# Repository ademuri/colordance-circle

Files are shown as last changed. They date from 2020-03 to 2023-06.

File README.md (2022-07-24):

# Colordance Circle

An art project that uses arrays of colored lights around a circle to create
kaleidoscopic colored shadows.

"This is not an officially supported Google product"

## Building

This project uses two build systems, PlatformIO and CMake. PIO is for code which
runs on embedded devices - these run the actual hardware. CMake is for running
tests on standard PCs.

To build with PlatformIO, run `pio run -e <env>`, where `<env>` is one defined
in [platformio.ini](platformio.ini) (e.g. `teensy`).

To run the tests:

```
mkdir -p build
cd build
cmake .. -DBUILD_SIMULATOR=false
make && ./generictest
```

### Simulator

The simulator uses SDL2 to render the LEDs. To build it, first install the SDL2 development library

`sudo apt install libsdl2-dev`

then, from the `build` directory, configure CMake to build it with

`cmake .. -DBUILD_SIMULATOR=true`

then build and run it with

`make && ./lib/simulator/Simulator`

#### Processing

To run the simulator with the Processing controller, from the build directory run:

```bash
${PROCESSING_HOME?}/processing-java --sketch=../controller/processing_controller --run | ./lib/simulator/Simulator
```

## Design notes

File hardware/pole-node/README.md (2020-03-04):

## Datasheets

- APA3211: [datasheet](https://www.diodes.com/assets/Datasheets/AP3211.pdf), [application notes](https://www.diodes.com/assets/Part-Support-Files/AP3211/6434133.pdf)

## Calculations

### Voltage regulator

- Feedback voltage is 0.81V. Use [this voltage divider calculator](http://www.ti.com/download/kbase/volt/volt_div3.htm). For E96, this yields 11500 and 2210 Ohms, which produces 5.02v.
- Inductor value: `L1 = 5V * (12V - 5V) / (1.4MHz * 12V * 1.5A * .26) = 5.3uH -> 5.6 uH`
- Peak inductor current: `1.5A + ((12V - 5V) * 5V) / (2 * 1.4MHz * 12V * 5.6uH) = 1.69A`
- Inductor current rating is `1.5 * 1.69A = 2.5A`
- Input ripple with 10uF cap: `1.5A / (1.4Mhz * 10uF) * (5V / 12V) * (1 - (5V / 12V)) = .026V`

### RS485 termination

- [Application note](http://www.ti.com/lit/an/snla034b/snla034b.pdf)
- AC termination should yield clean signal without significantly increasing power consumption
- Assuming 40' max cable length:
- `C<sub>T <= (40ft * 2 * 1.7ns/ft) / 100 Ohm = 1.36 nF`
- This yields an RC time constant of `136 ns`. At `800 kHz`, the signal period is `1.25 us`.

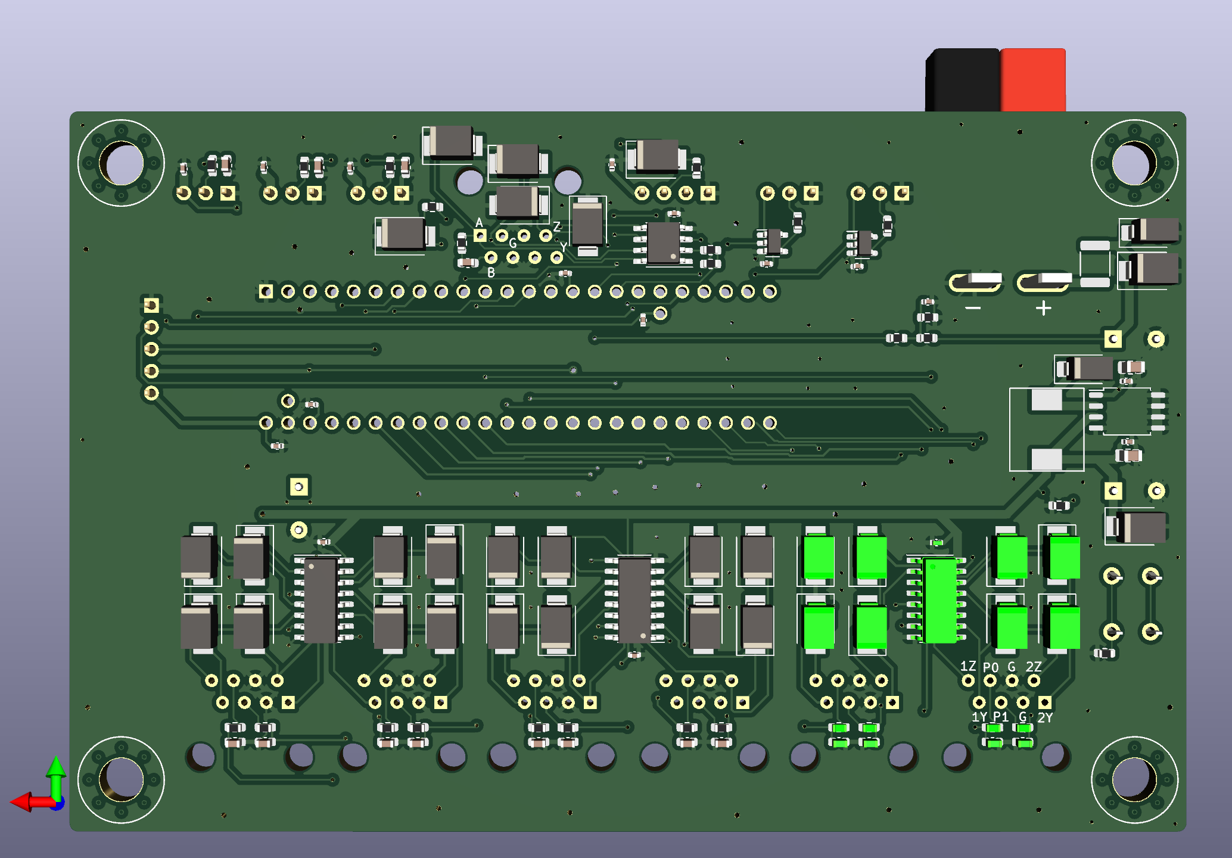
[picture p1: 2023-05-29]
hardware/colordance-brain/ref/colordance-brain back.png

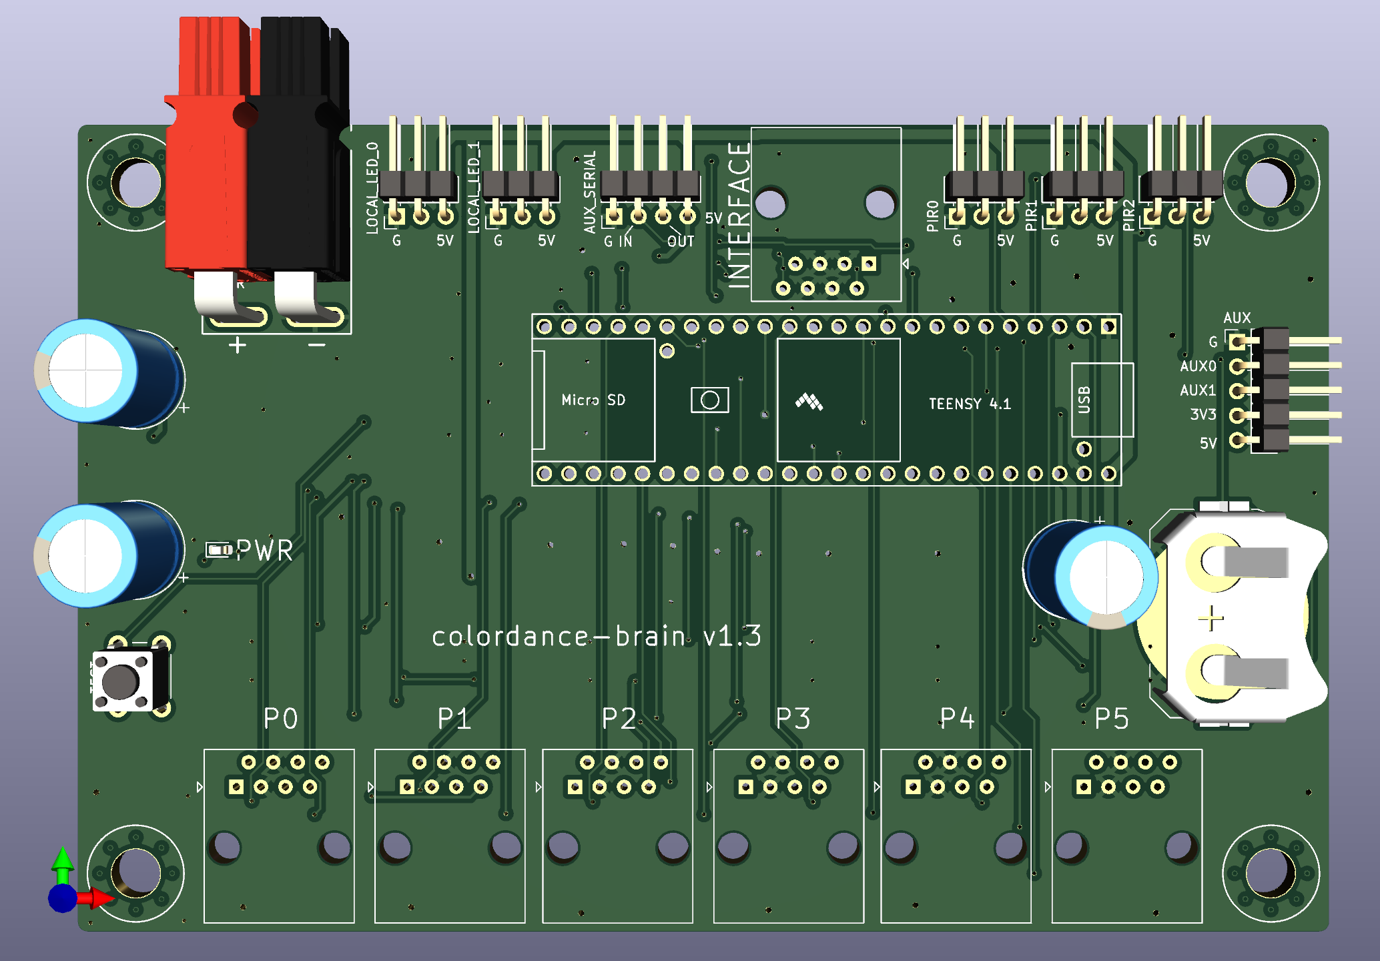
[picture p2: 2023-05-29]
hardware/colordance-brain/ref/colordance-brain front.png

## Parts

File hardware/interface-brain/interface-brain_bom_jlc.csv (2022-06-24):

Comment | Designator | Footprint | LCSC Part #
100nF | C1,C2,C3,C4,C8,C9,C10,C11,C12,C13,C14,C15,C16,C17,C18,C19,C20,C21,C22,C23,C28,C29,C30,C31,C32,C33,C34,C35,C40,C41,C42,C43,C48,C49,C50,C51,C55,C58,C60 | C_0402_1005Metric | C307331
10nF | C7 | C_0402_1005Metric | C15195
22nF | C24,C25,C26,C27,C36,C37,C38,C39,C44,C45,C46,C47,C52,C53 | C_0402_1005Metric | C1532
22uF | C54 | C_1206_3216Metric | C12891
1nF | C57 | C_0402_1005Metric | C1523
10uF | C61,C6,C59 | C_0805_2012Metric | C15850
SCHOTTKY | D2 | D_SMA | C8678
LED | D6 | LED_0603_1608Metric | C2286
D | D9 | D_SMA | C8678
10k | R1,R2,R3,R4,R25 | R_0603_1608Metric | C25804
120 | R7 | R_0603_1608Metric | C22787
33 | R9,R10,R11,R12,R13,R14,R15,R16,R17,R18,R19,R20,R21,R22,R23,R24 | R_0603_1608Metric | C23140
1k | R26,R27,R28,R29,R30,R31,R32,R33,R38,R39,R40,R41,R42,R43,R44,R45,R46,R47,R48,R49,R54,R55 | R_0603_1608Metric | C21190
SN74ACT244PWR | U1,U2 | TSSOP-20_4.4x6.5mm_P0.65mm | C6930

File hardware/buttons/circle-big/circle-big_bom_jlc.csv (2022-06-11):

Comment | Designator | Footprint | LCSC Part #
10uF | C1 | C_0603_1608Metric | C96446
100nF | C2 | C_0402_1005Metric | C307331
WS2812B | D1,D2,D3,D4,D5,D6,D7,D8,D9,D10,D11,D12 | LED_WS2812B_PLCC4_5.0x5.0mm_P3.2mm | C2761796
33 | R1,R2 | R_0603_1608Metric | C23140

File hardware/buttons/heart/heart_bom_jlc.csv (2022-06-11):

Comment | Designator | Footprint | LCSC Part #
10uF | C1 | C_0603_1608Metric | C96446
100nF | C2 | C_0402_1005Metric | C307331
WS2812B | D1,D2,D3,D4,D5,D6,D7,D8,D9,D10,D11,D12,D13,D14,D15 | LED_WS2812B_PLCC4_5.0x5.0mm_P3.2mm | C2761796
33 | R1,R2 | R_0603_1608Metric | C23140

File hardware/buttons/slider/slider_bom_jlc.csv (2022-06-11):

Comment | Designator | Footprint | LCSC Part #
10uF | C1 | C_0603_1608Metric | C96446
100nF | C2 | C_0402_1005Metric | C307331
WS2812B | D1,D2,D3 | LED_WS2812B_PLCC4_5.0x5.0mm_P3.2mm | C2761796
33 | R1 | R_0603_1608Metric | C23140

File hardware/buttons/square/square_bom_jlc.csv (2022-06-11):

Comment | Designator | Footprint | LCSC Part #
10uF | C1 | C_0603_1608Metric | C96446
100nF | C2 | C_0402_1005Metric | C307331
WS2812B | D1,D2,D3,D4 | LED_WS2812B_PLCC4_5.0x5.0mm_P3.2mm | C2761796
33 | R1,R2 | R_0603_1608Metric | C23140

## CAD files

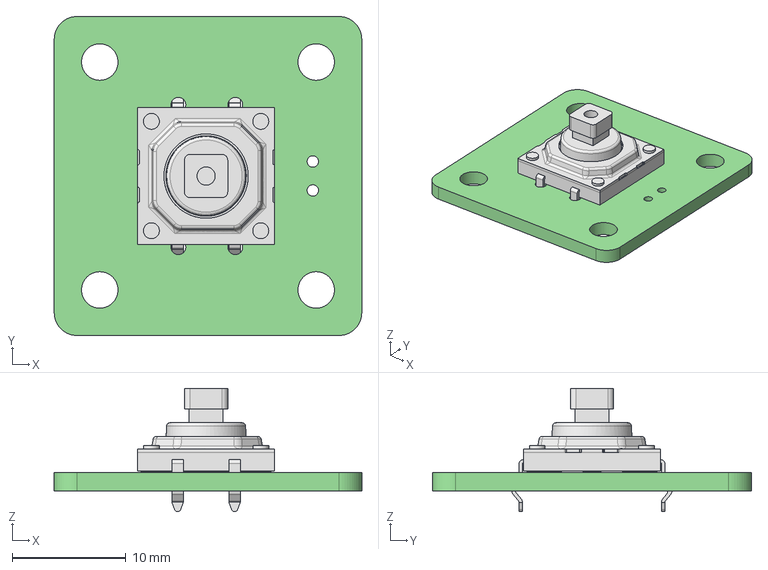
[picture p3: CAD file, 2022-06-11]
hardware/buttons/button-holder/button-holder.step
27.0 x 28.0 x 10.8 mm
button-holder PCB

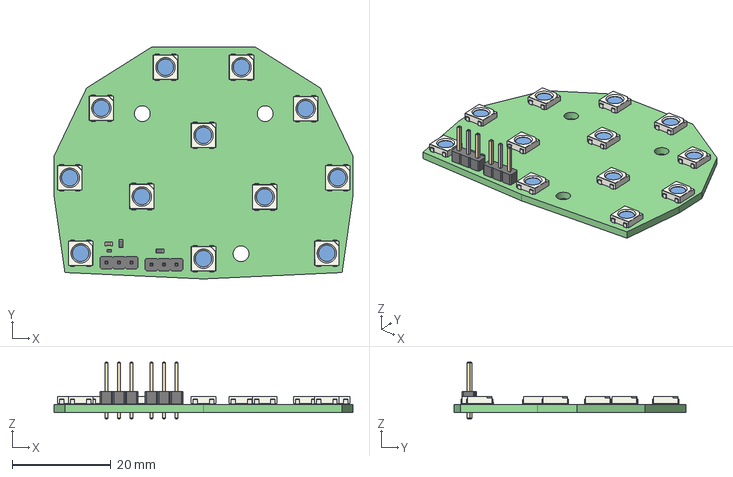
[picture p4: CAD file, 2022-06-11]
hardware/buttons/circle-big/circle-big.step
60.6 x 47.0 x 11.5 mm
circle-big PCB

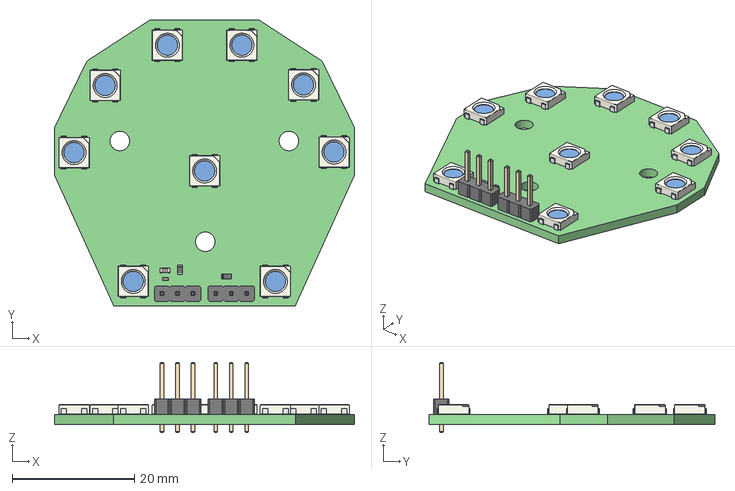
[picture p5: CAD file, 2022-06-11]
hardware/buttons/circle-small/circle-small.step
49.1 x 46.8 x 11.5 mm
circle-small PCB

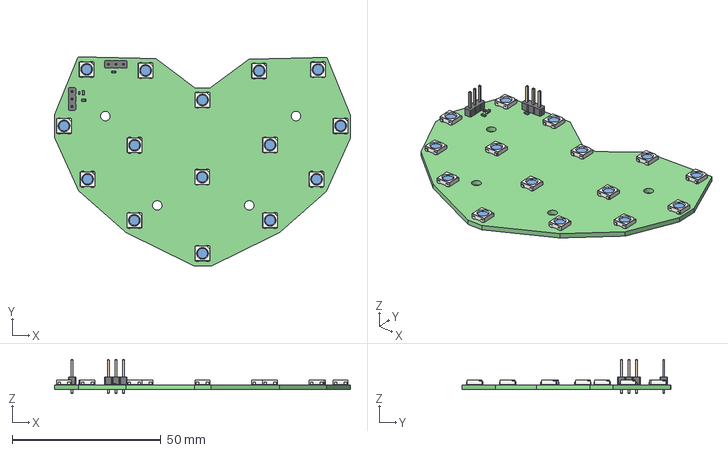
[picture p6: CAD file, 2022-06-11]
hardware/buttons/heart/heart.step
99.4 x 70.3 x 11.5 mm
heart PCB

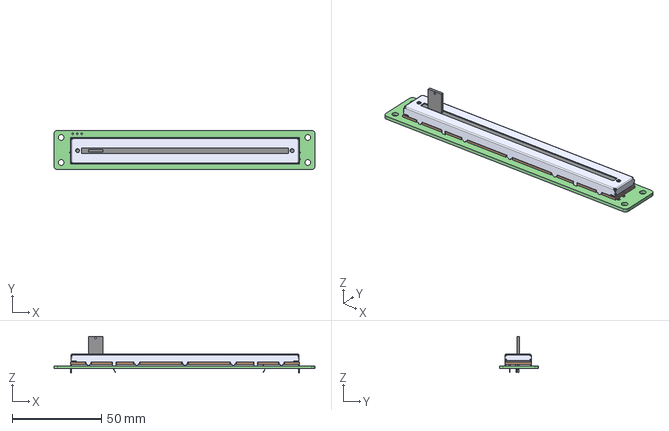
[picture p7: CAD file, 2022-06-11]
hardware/buttons/pot-holder/pot-holder.step
146.0 x 22.0 x 20.4 mm
pot-holder PCB

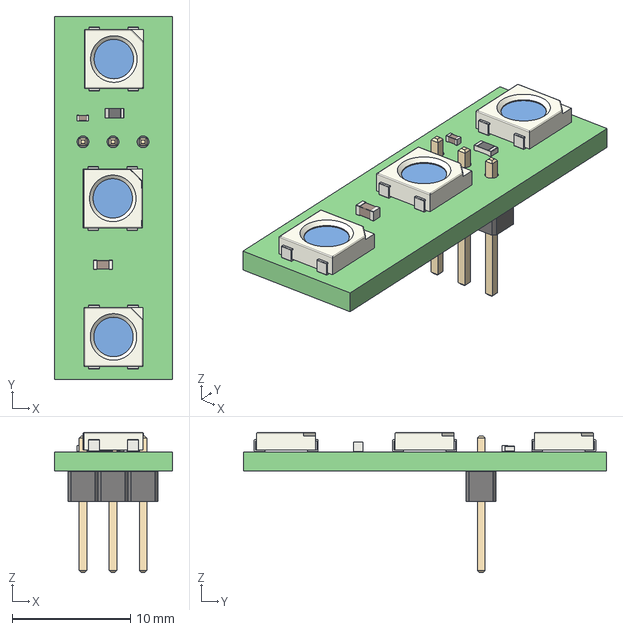
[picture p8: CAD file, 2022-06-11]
hardware/buttons/slider/slider.step
10.0 x 30.7 x 11.8 mm
slider PCB

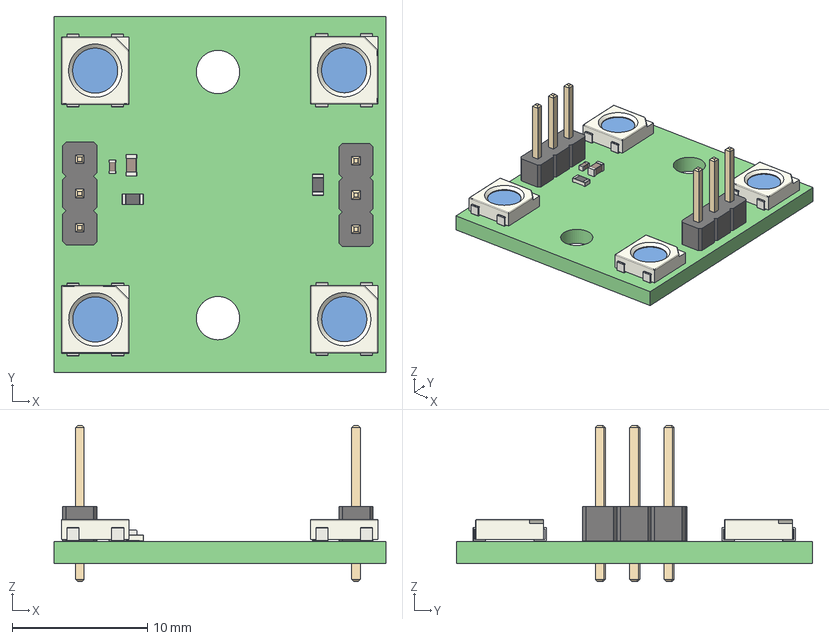
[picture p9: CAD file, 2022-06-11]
hardware/buttons/square/square.step
24.5 x 26.3 x 11.5 mm
square PCB

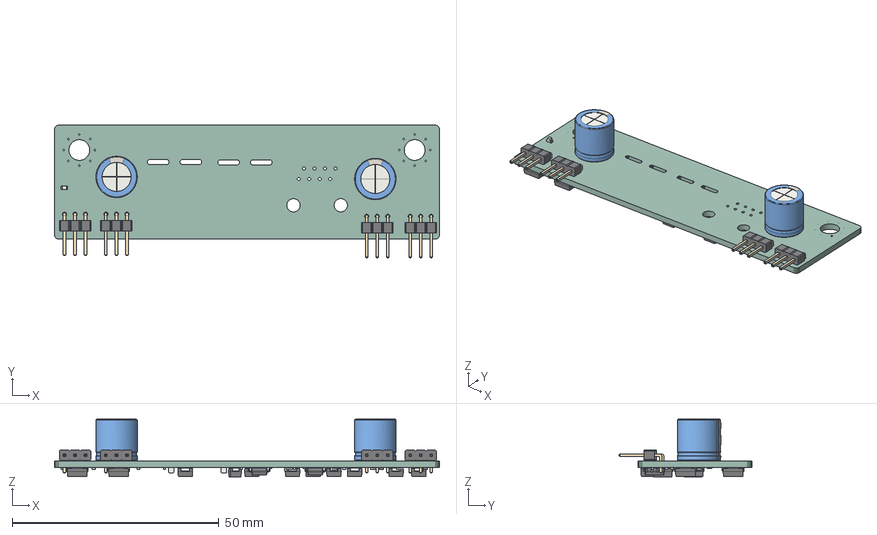
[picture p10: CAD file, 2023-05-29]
hardware/pole-node/ref/pole-node.step
93.0 x 32.0 x 13.9 mm
_autosave-pole-node PCB

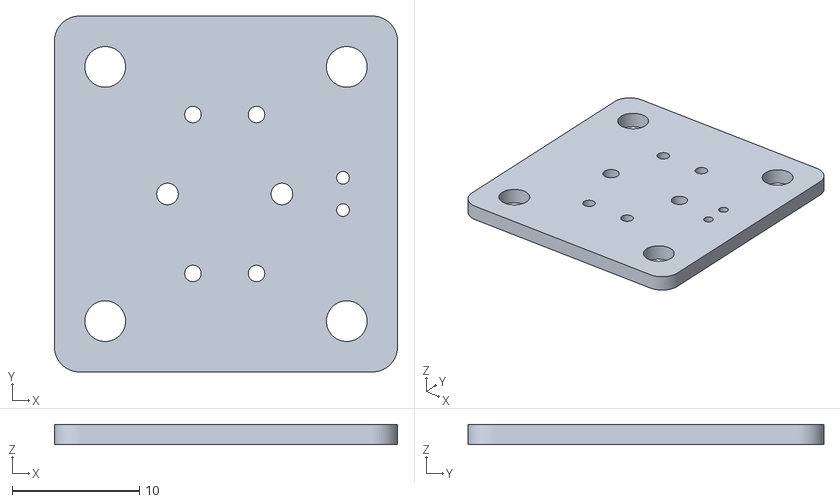
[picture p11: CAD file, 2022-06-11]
hardware/buttons/button-holder/button-holder PCB.stl
27.0 x 28.0 x 1.60

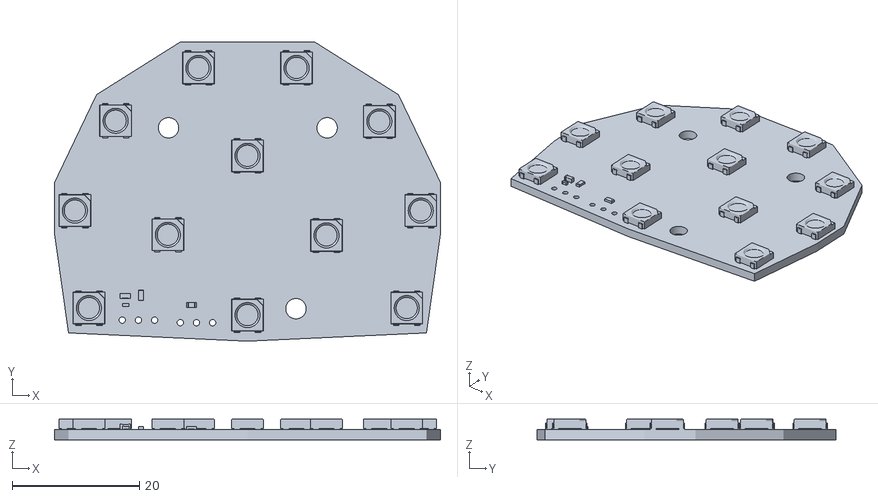
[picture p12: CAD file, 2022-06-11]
hardware/buttons/circle-big/circle-big v1.stl
60.6 x 47.0 x 3.25

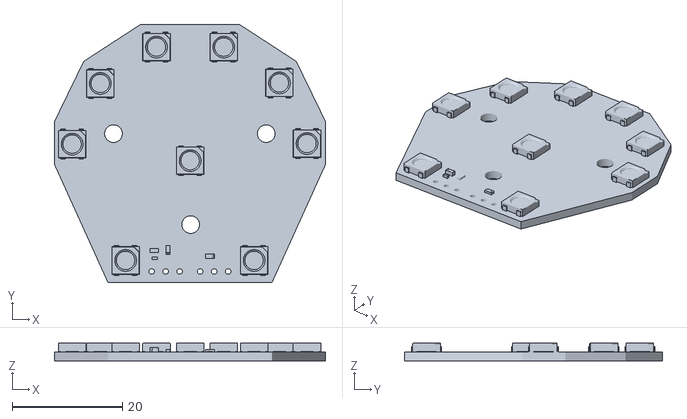
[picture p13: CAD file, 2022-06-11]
hardware/buttons/circle-small/circle-small v1.stl
49.2 x 46.8 x 3.25

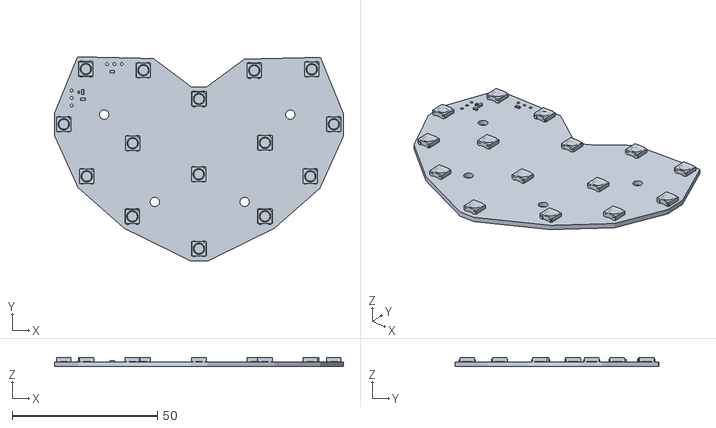
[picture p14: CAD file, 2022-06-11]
hardware/buttons/heart/heart v1.stl
99.4 x 70.3 x 3.25

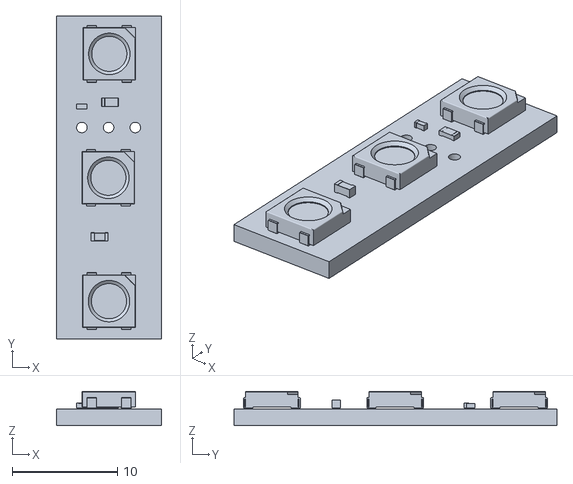
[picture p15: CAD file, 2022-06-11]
hardware/buttons/slider/slider v1.stl
10.0 x 30.7 x 3.25

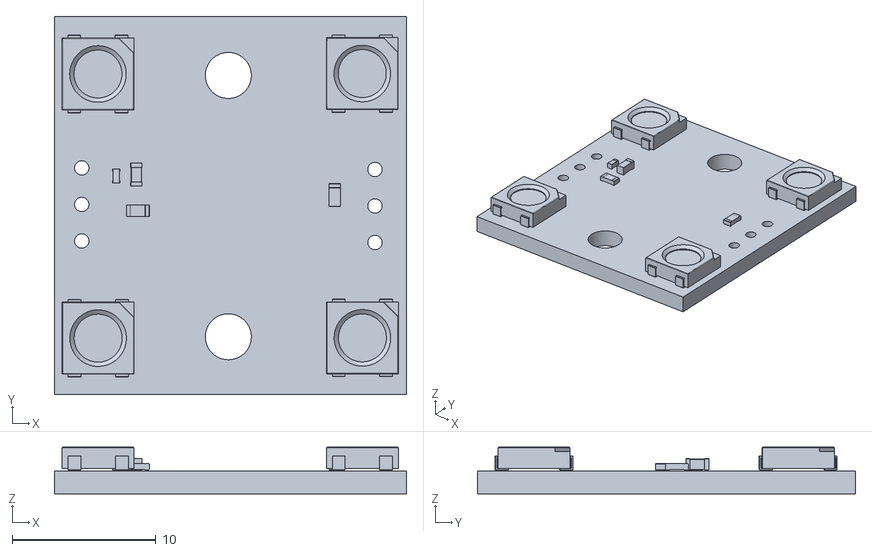
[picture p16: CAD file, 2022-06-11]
hardware/buttons/square/square v1.stl
24.5 x 26.3 x 3.25

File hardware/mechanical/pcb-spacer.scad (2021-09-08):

$fn = 200;

function inches(in) = in * 25.4;

module spacer(height, id, od) {
    linear_extrude(height = height) {
        difference() {
            circle(d = od);
            circle(d = id);
        }
    }
}

// #8 PCB spacer
//spacer(height = 6.35, od = 5 + 2 * 4, id = 5);

// 1/4-20 bolt washer
spacer(height = 1, id = inches(.257), od = inches(.257) + 2 * 4);

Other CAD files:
hardware/mechanical/pcb-spacer.stl
hardware/mechanical/quarter inch washer.stl

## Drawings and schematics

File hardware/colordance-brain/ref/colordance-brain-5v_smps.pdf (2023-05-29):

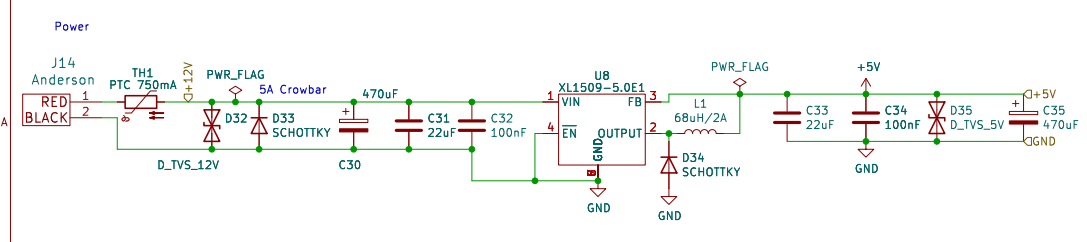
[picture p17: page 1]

Id: 5/5 Title: File: 5v_smps.kicad_sch Sheet: /5v_smps/

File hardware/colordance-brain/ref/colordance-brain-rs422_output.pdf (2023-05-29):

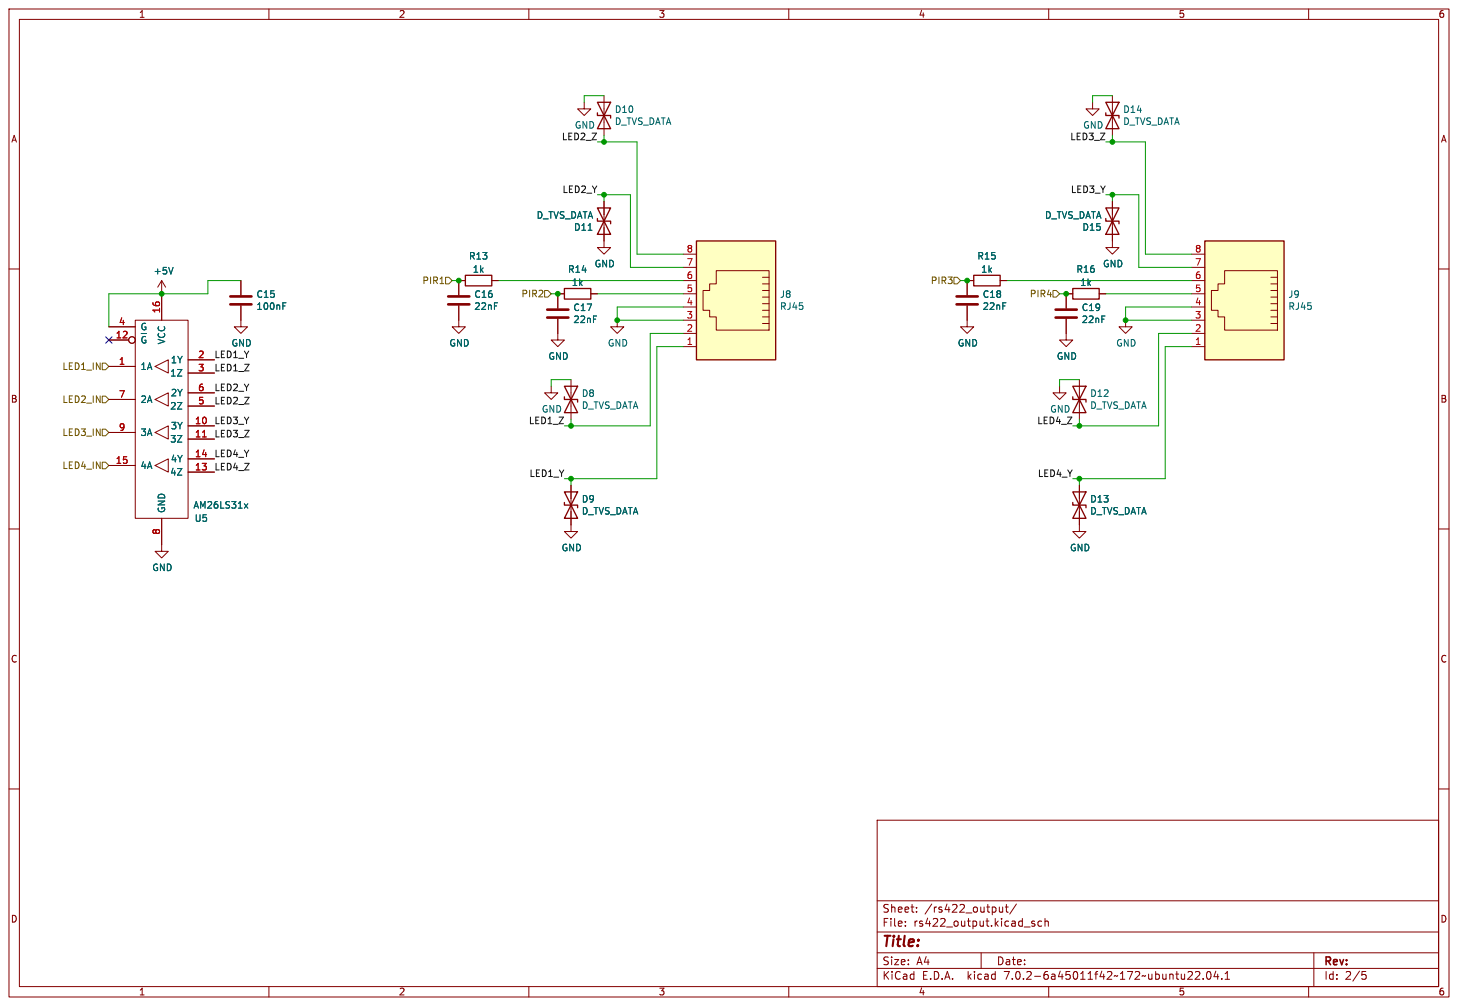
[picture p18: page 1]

Id: 2/5 Title: File: rs422_output.kicad_sch Sheet: /rs422_output/

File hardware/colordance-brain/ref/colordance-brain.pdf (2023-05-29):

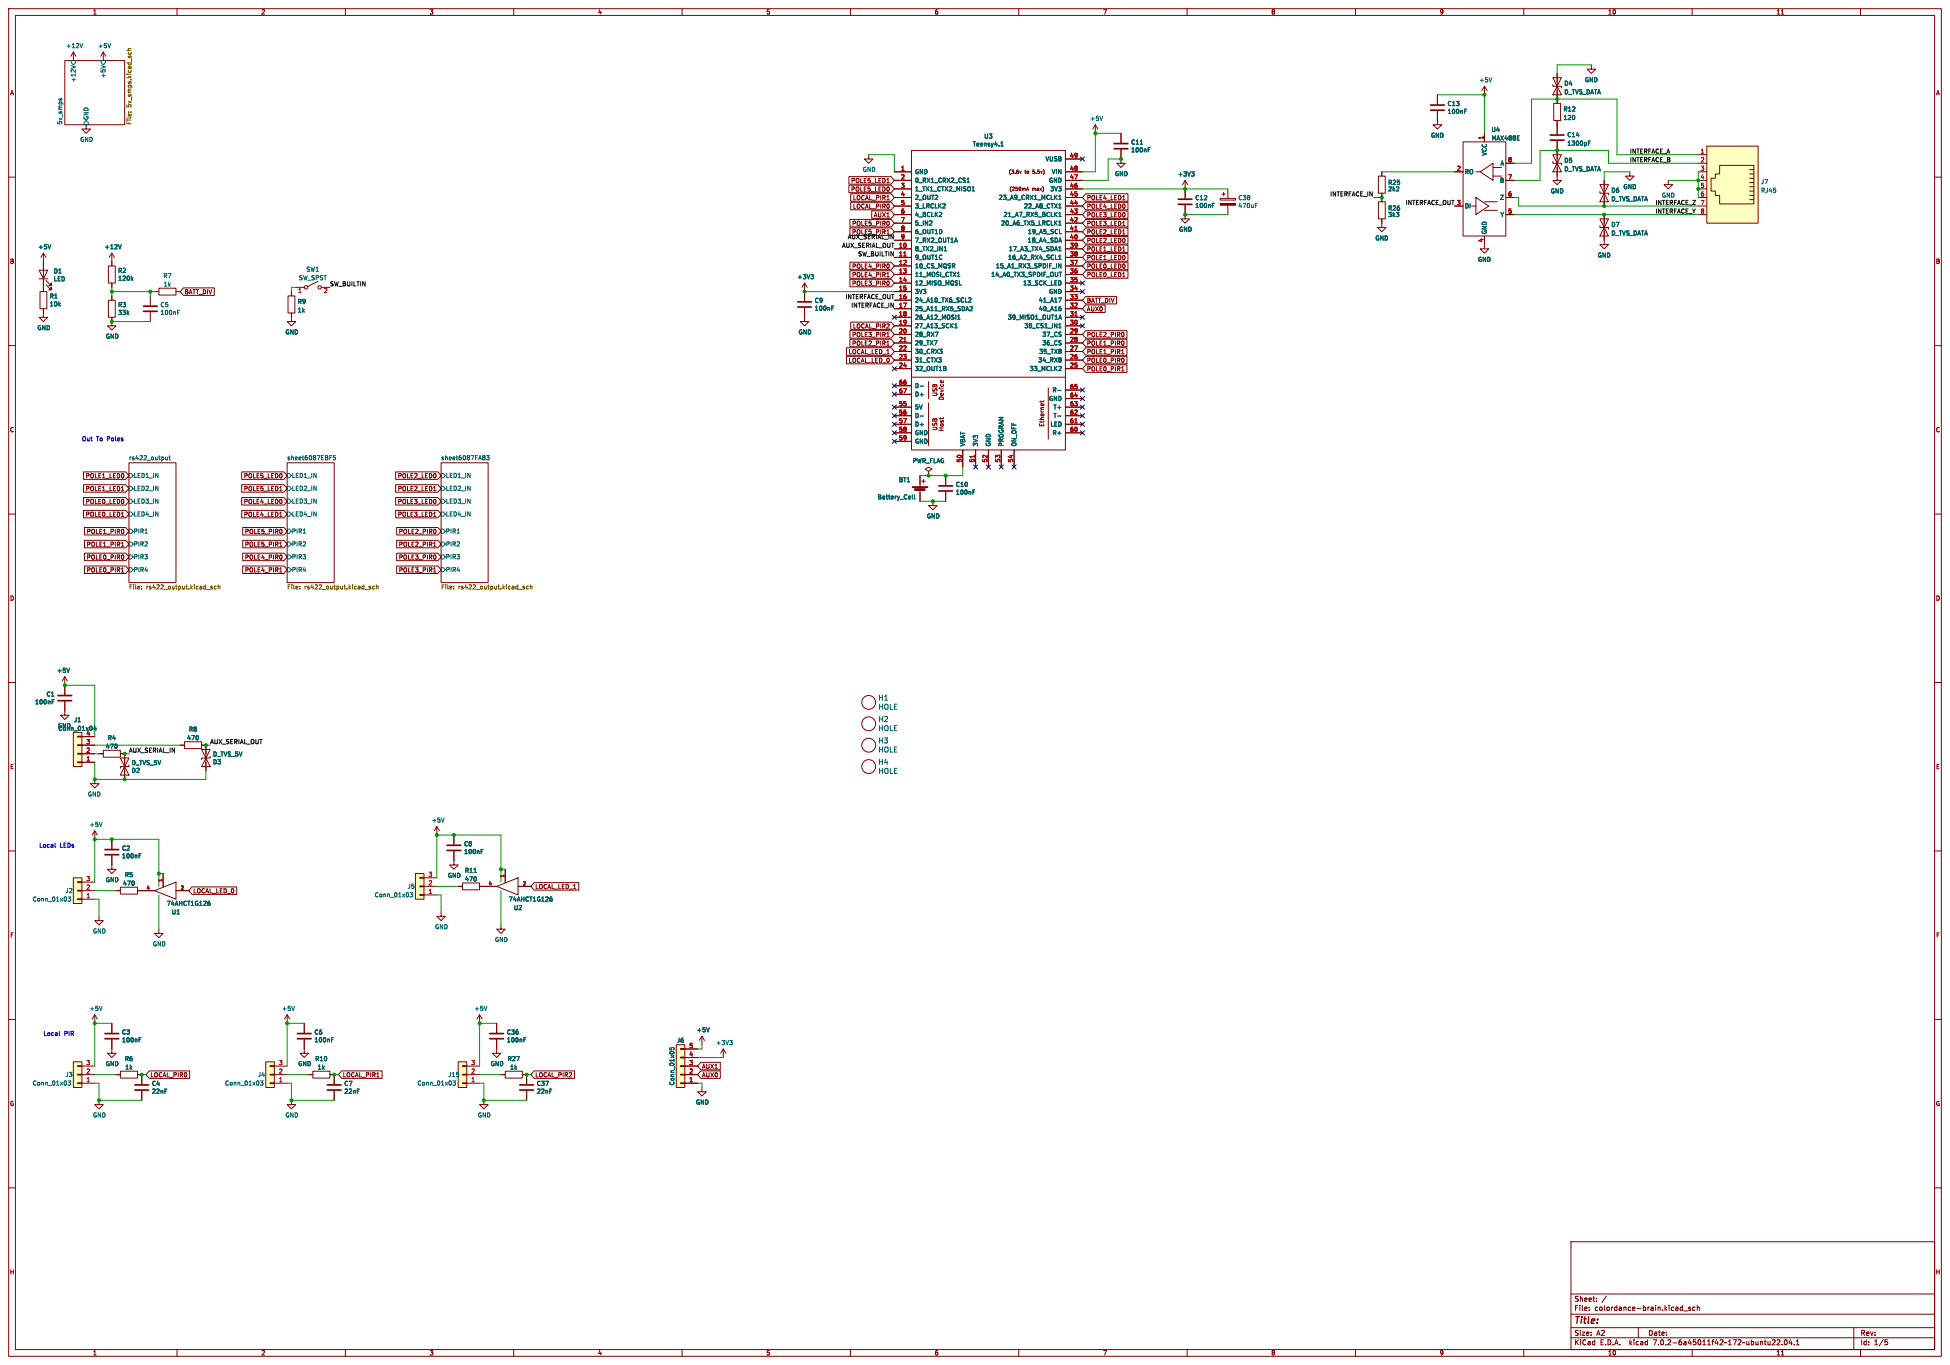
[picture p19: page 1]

GND
Local LEDs Local PIR

Id: 1/5 Title: File: colordance-brain.kicad_sch Sheet: /

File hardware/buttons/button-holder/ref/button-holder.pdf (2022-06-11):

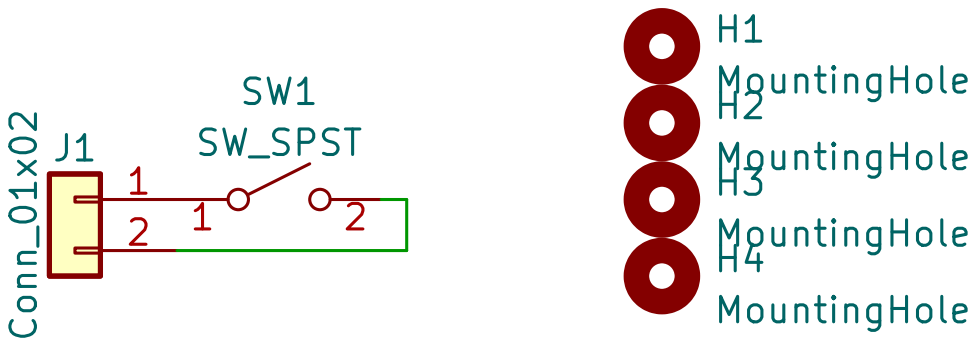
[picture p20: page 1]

File: button-holder.kicad_sch Sheet: /
Id: 1/1 Title:

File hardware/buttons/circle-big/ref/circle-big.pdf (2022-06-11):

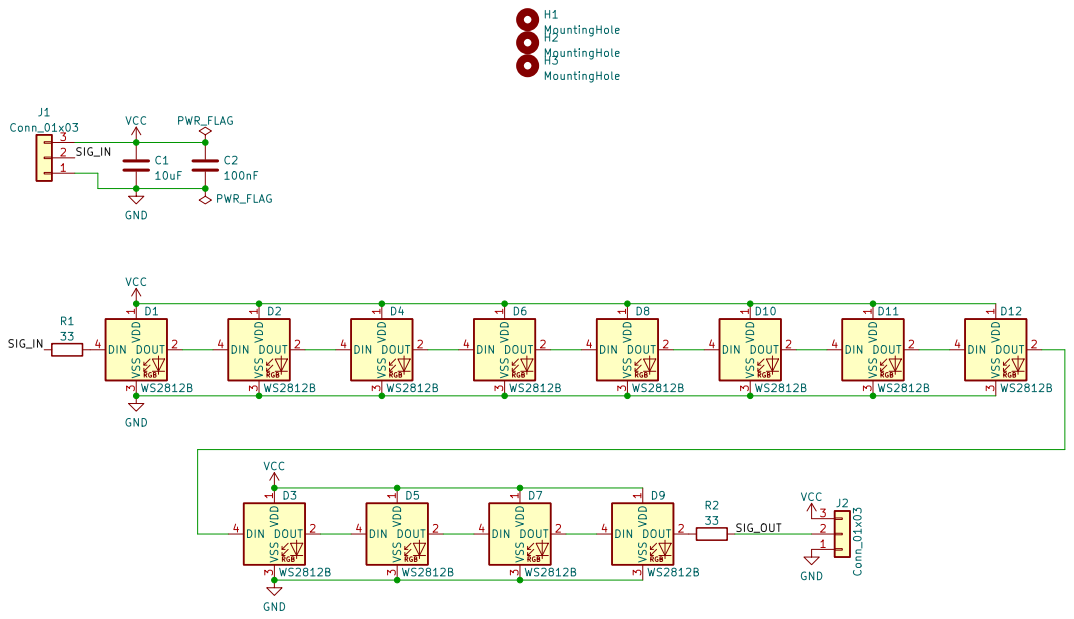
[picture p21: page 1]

File: circle-big.kicad_sch Sheet: /
Id: 1/1 Title:

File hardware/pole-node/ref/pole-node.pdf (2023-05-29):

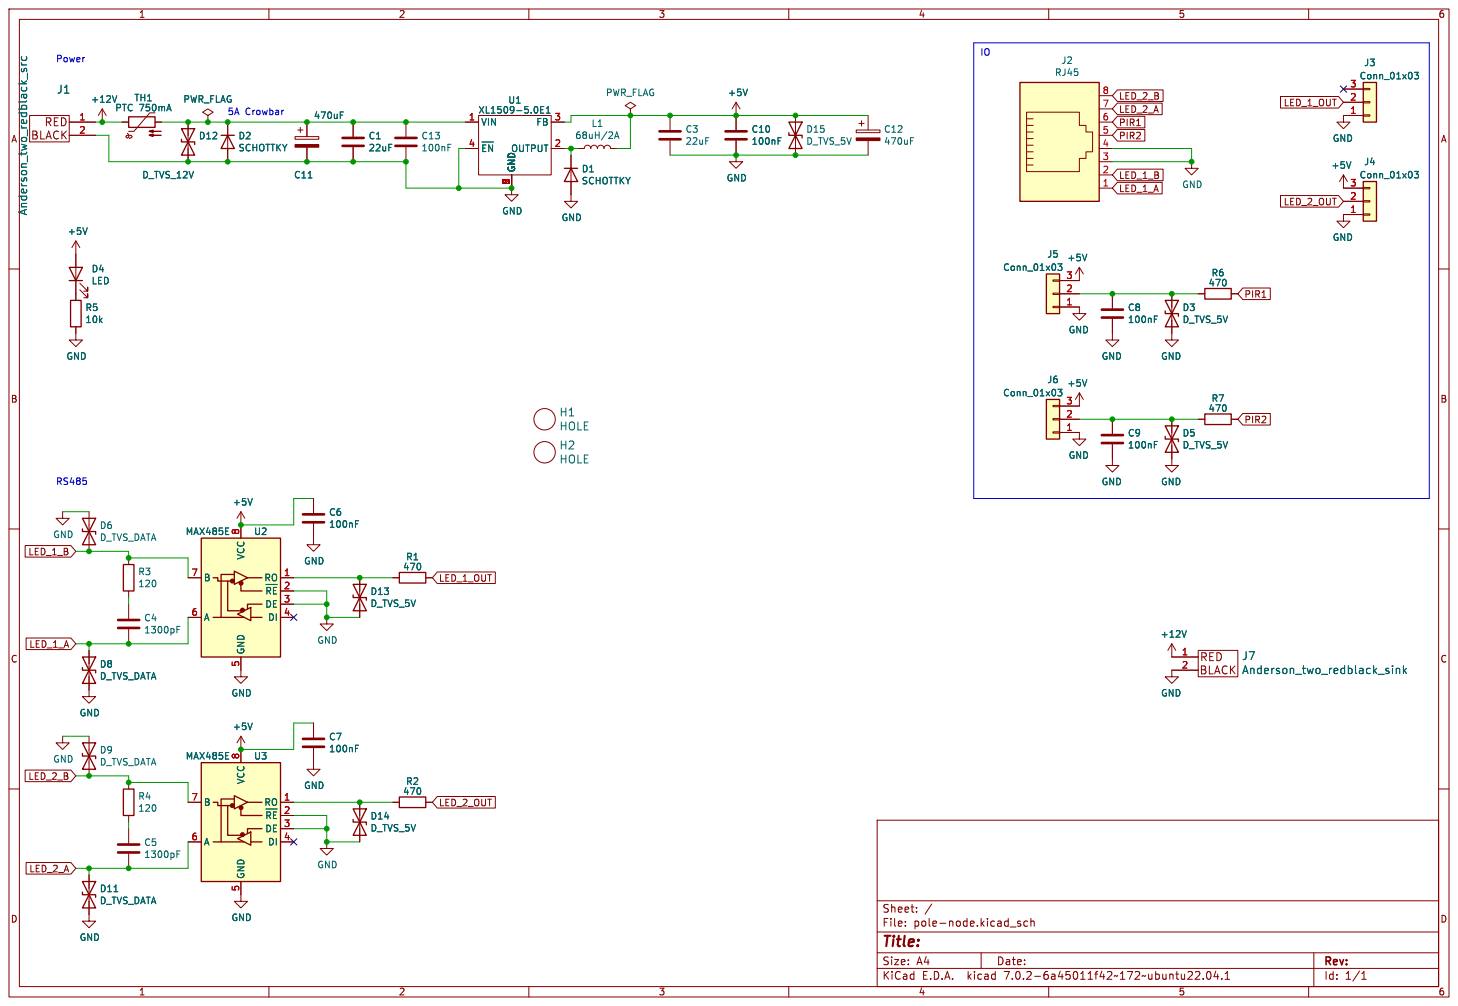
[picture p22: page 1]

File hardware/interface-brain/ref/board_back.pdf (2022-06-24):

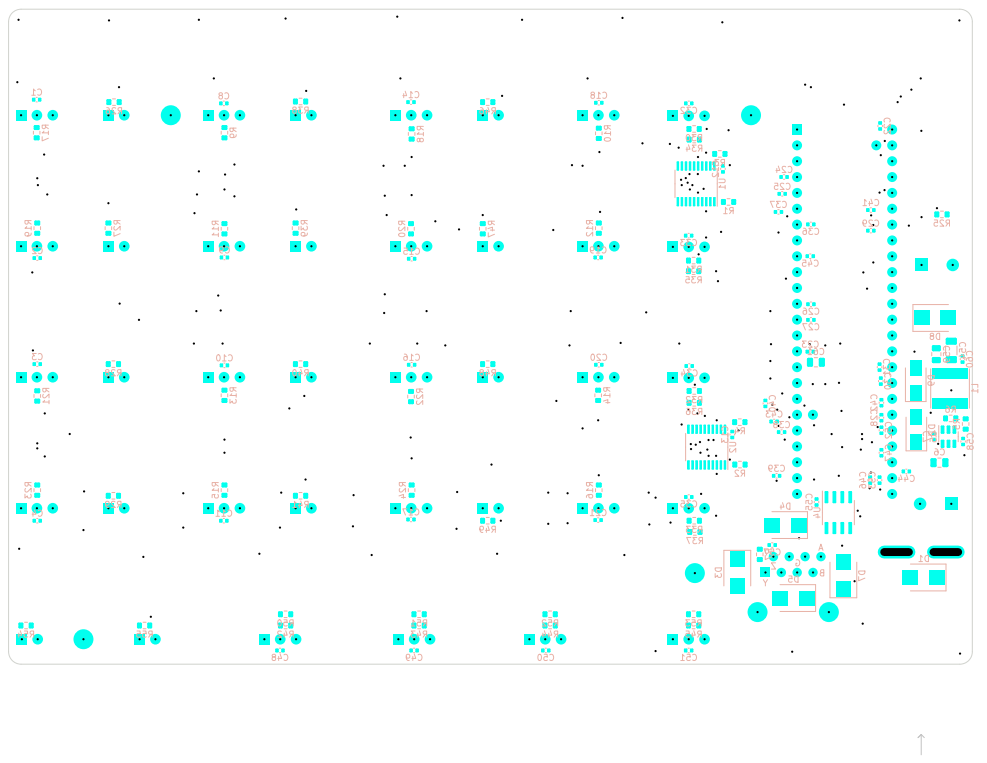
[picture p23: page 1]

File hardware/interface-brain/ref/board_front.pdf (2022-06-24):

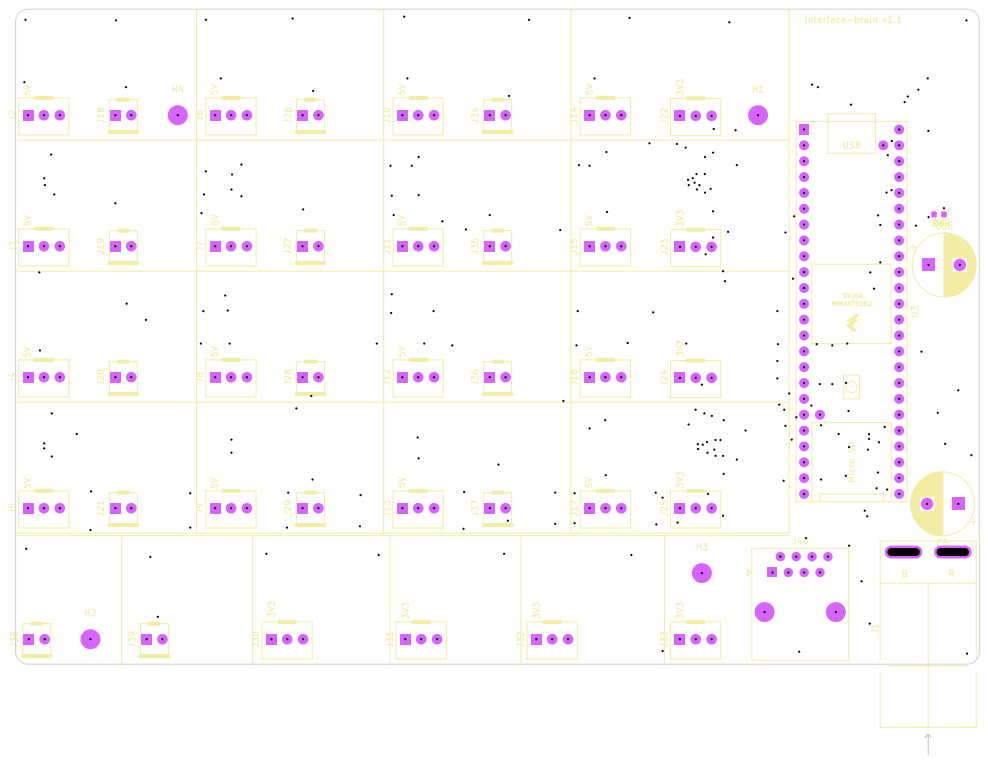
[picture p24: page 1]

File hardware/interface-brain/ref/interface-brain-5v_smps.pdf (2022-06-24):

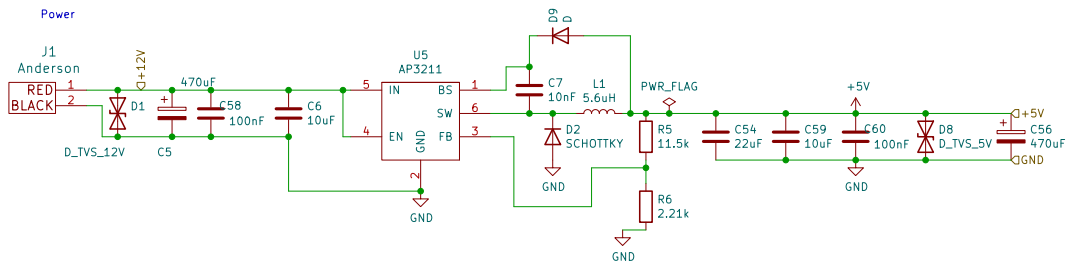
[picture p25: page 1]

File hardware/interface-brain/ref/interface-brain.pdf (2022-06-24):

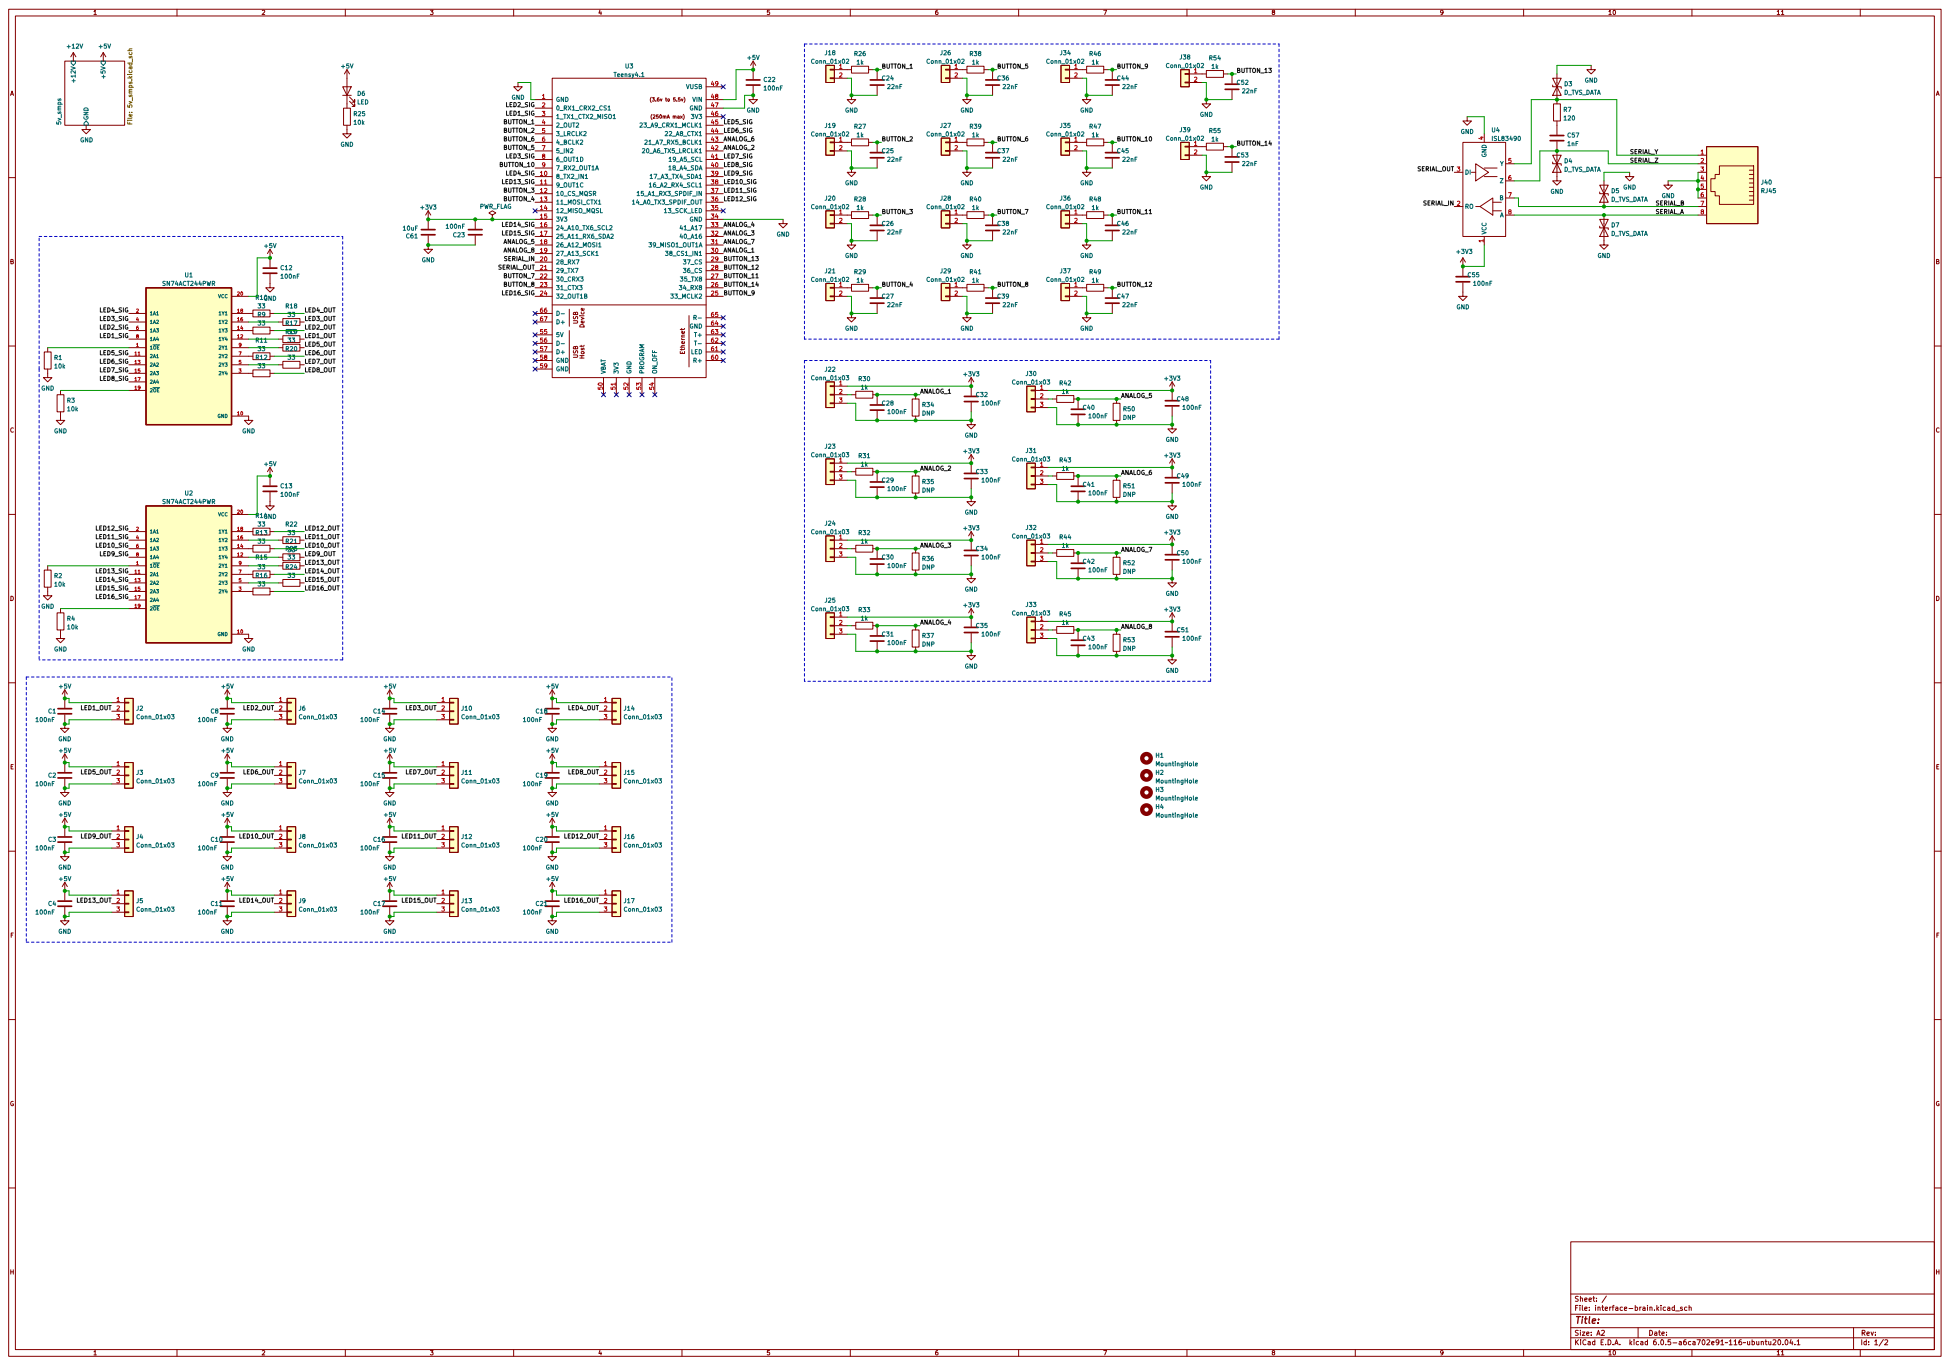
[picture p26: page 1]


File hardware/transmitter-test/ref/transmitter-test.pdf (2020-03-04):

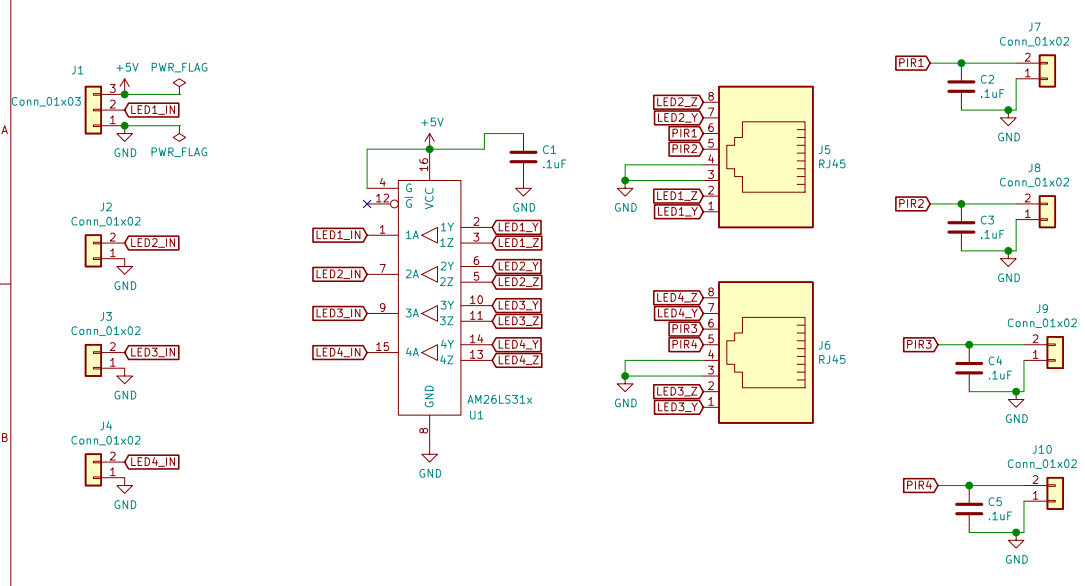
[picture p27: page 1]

Id: 1/1 Title: File: transmitter-test.sch Sheet: /

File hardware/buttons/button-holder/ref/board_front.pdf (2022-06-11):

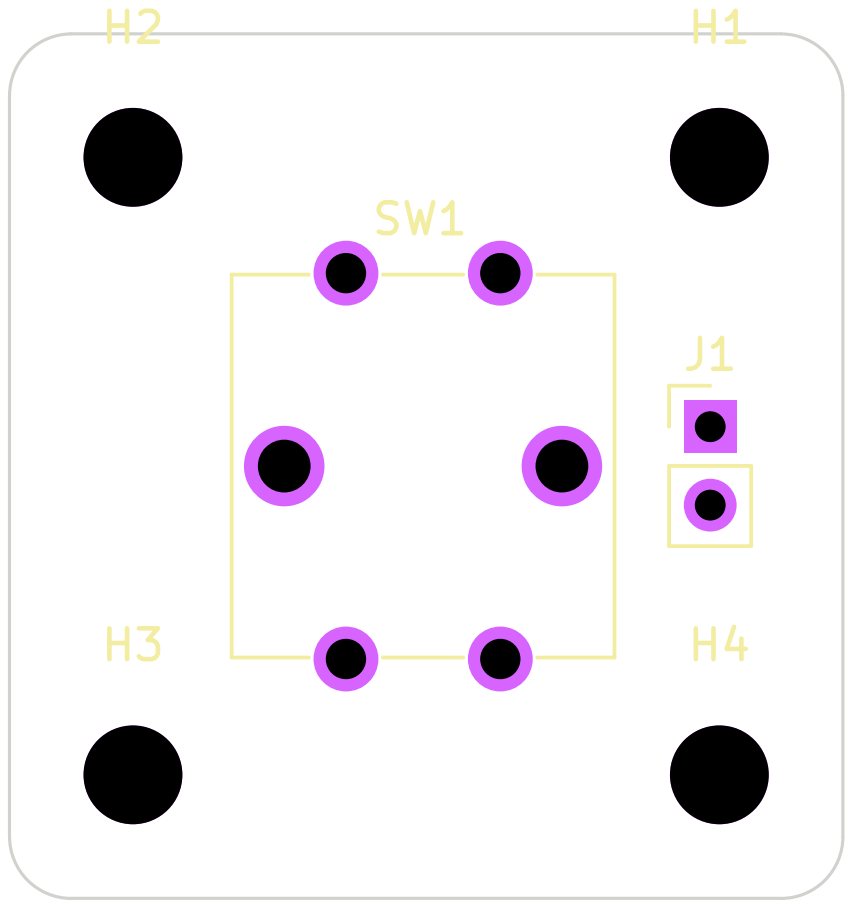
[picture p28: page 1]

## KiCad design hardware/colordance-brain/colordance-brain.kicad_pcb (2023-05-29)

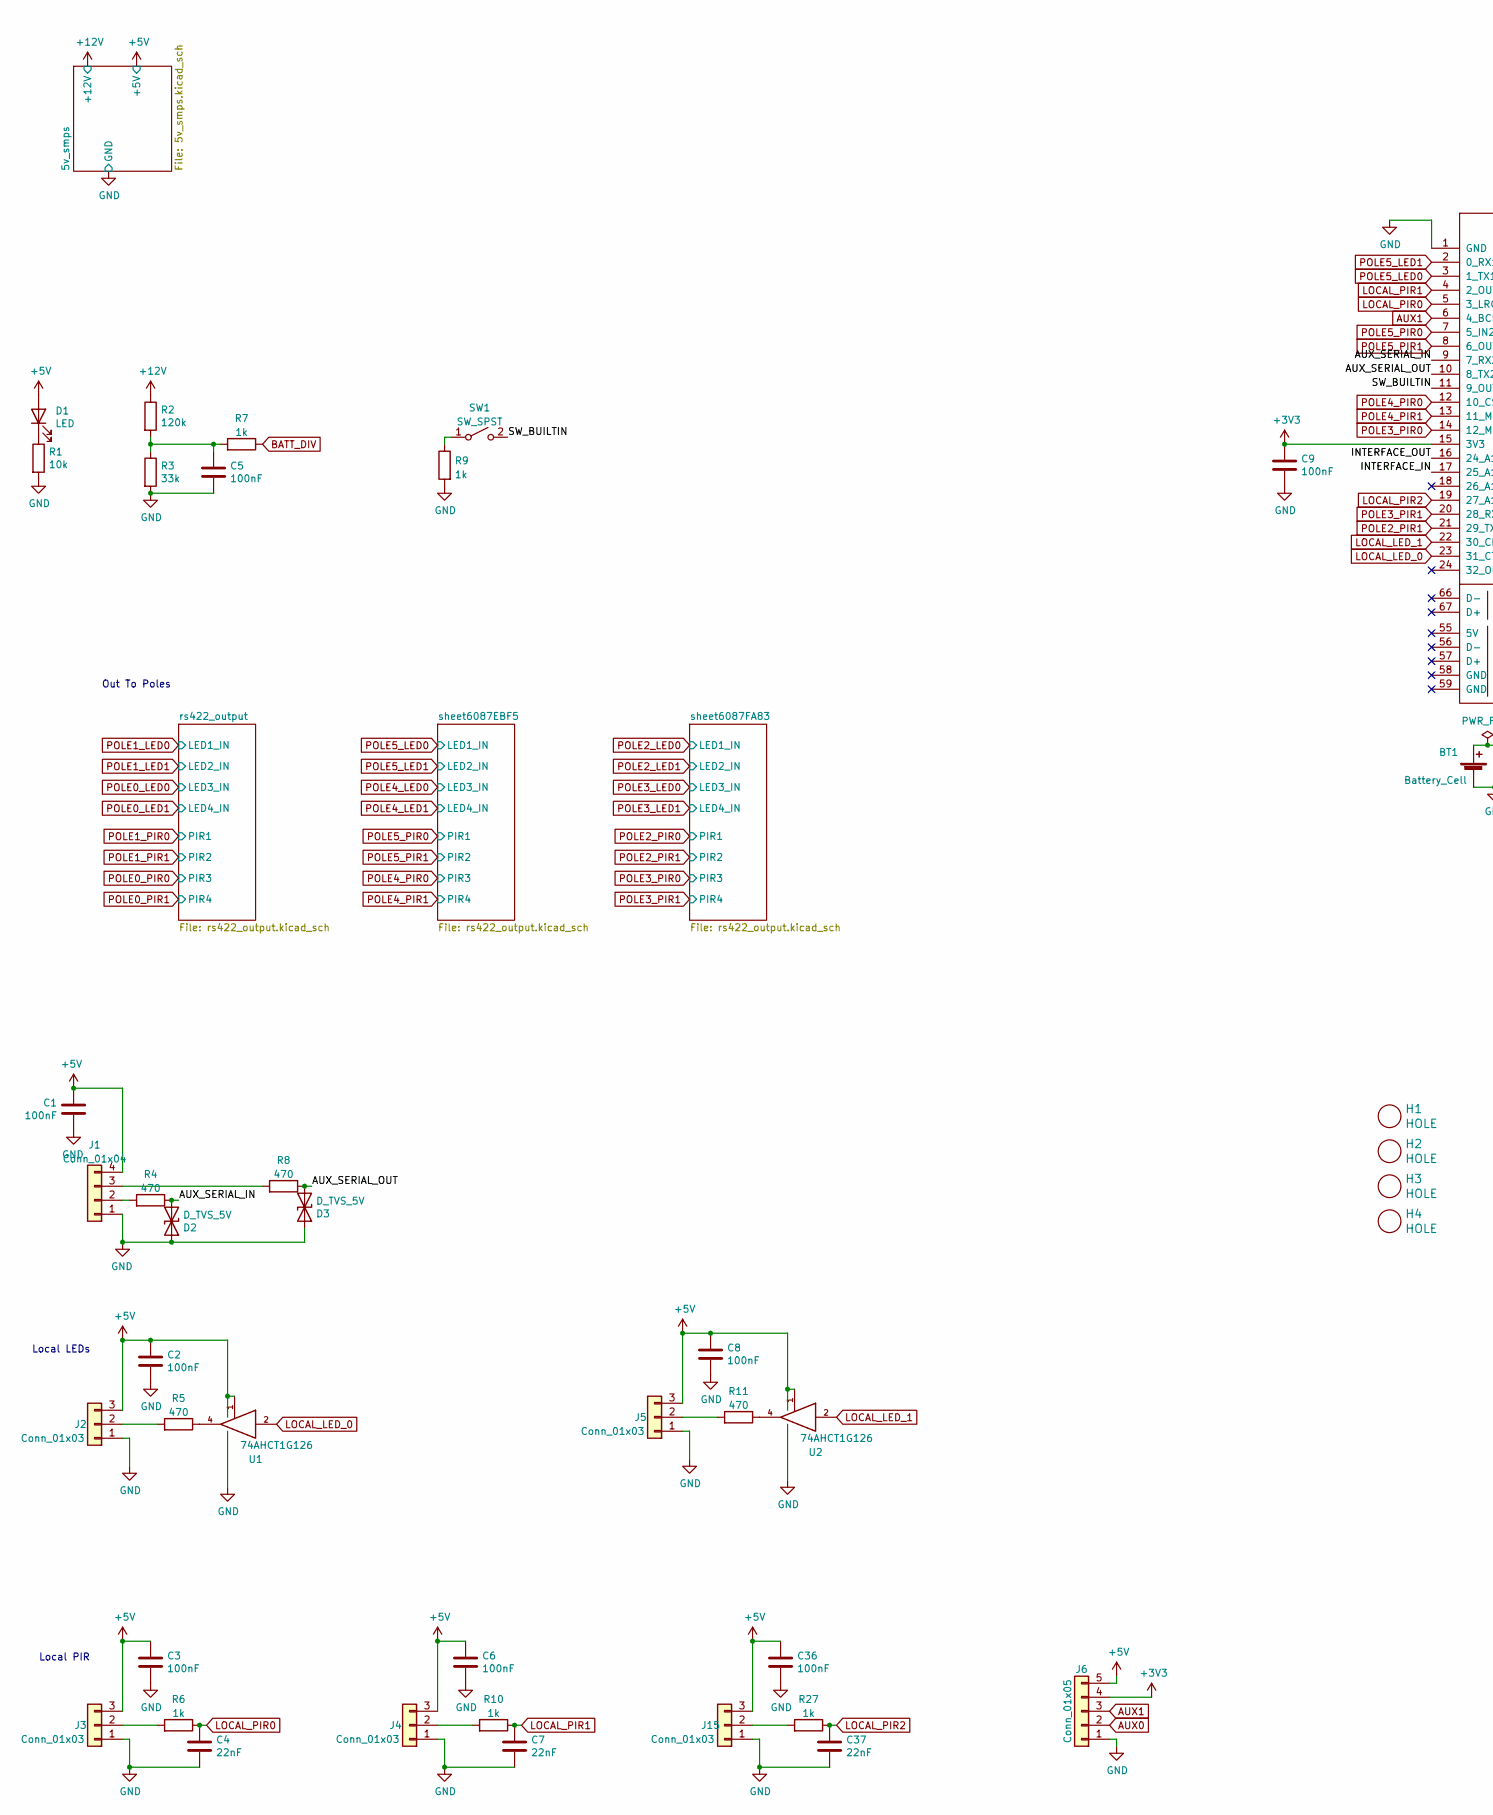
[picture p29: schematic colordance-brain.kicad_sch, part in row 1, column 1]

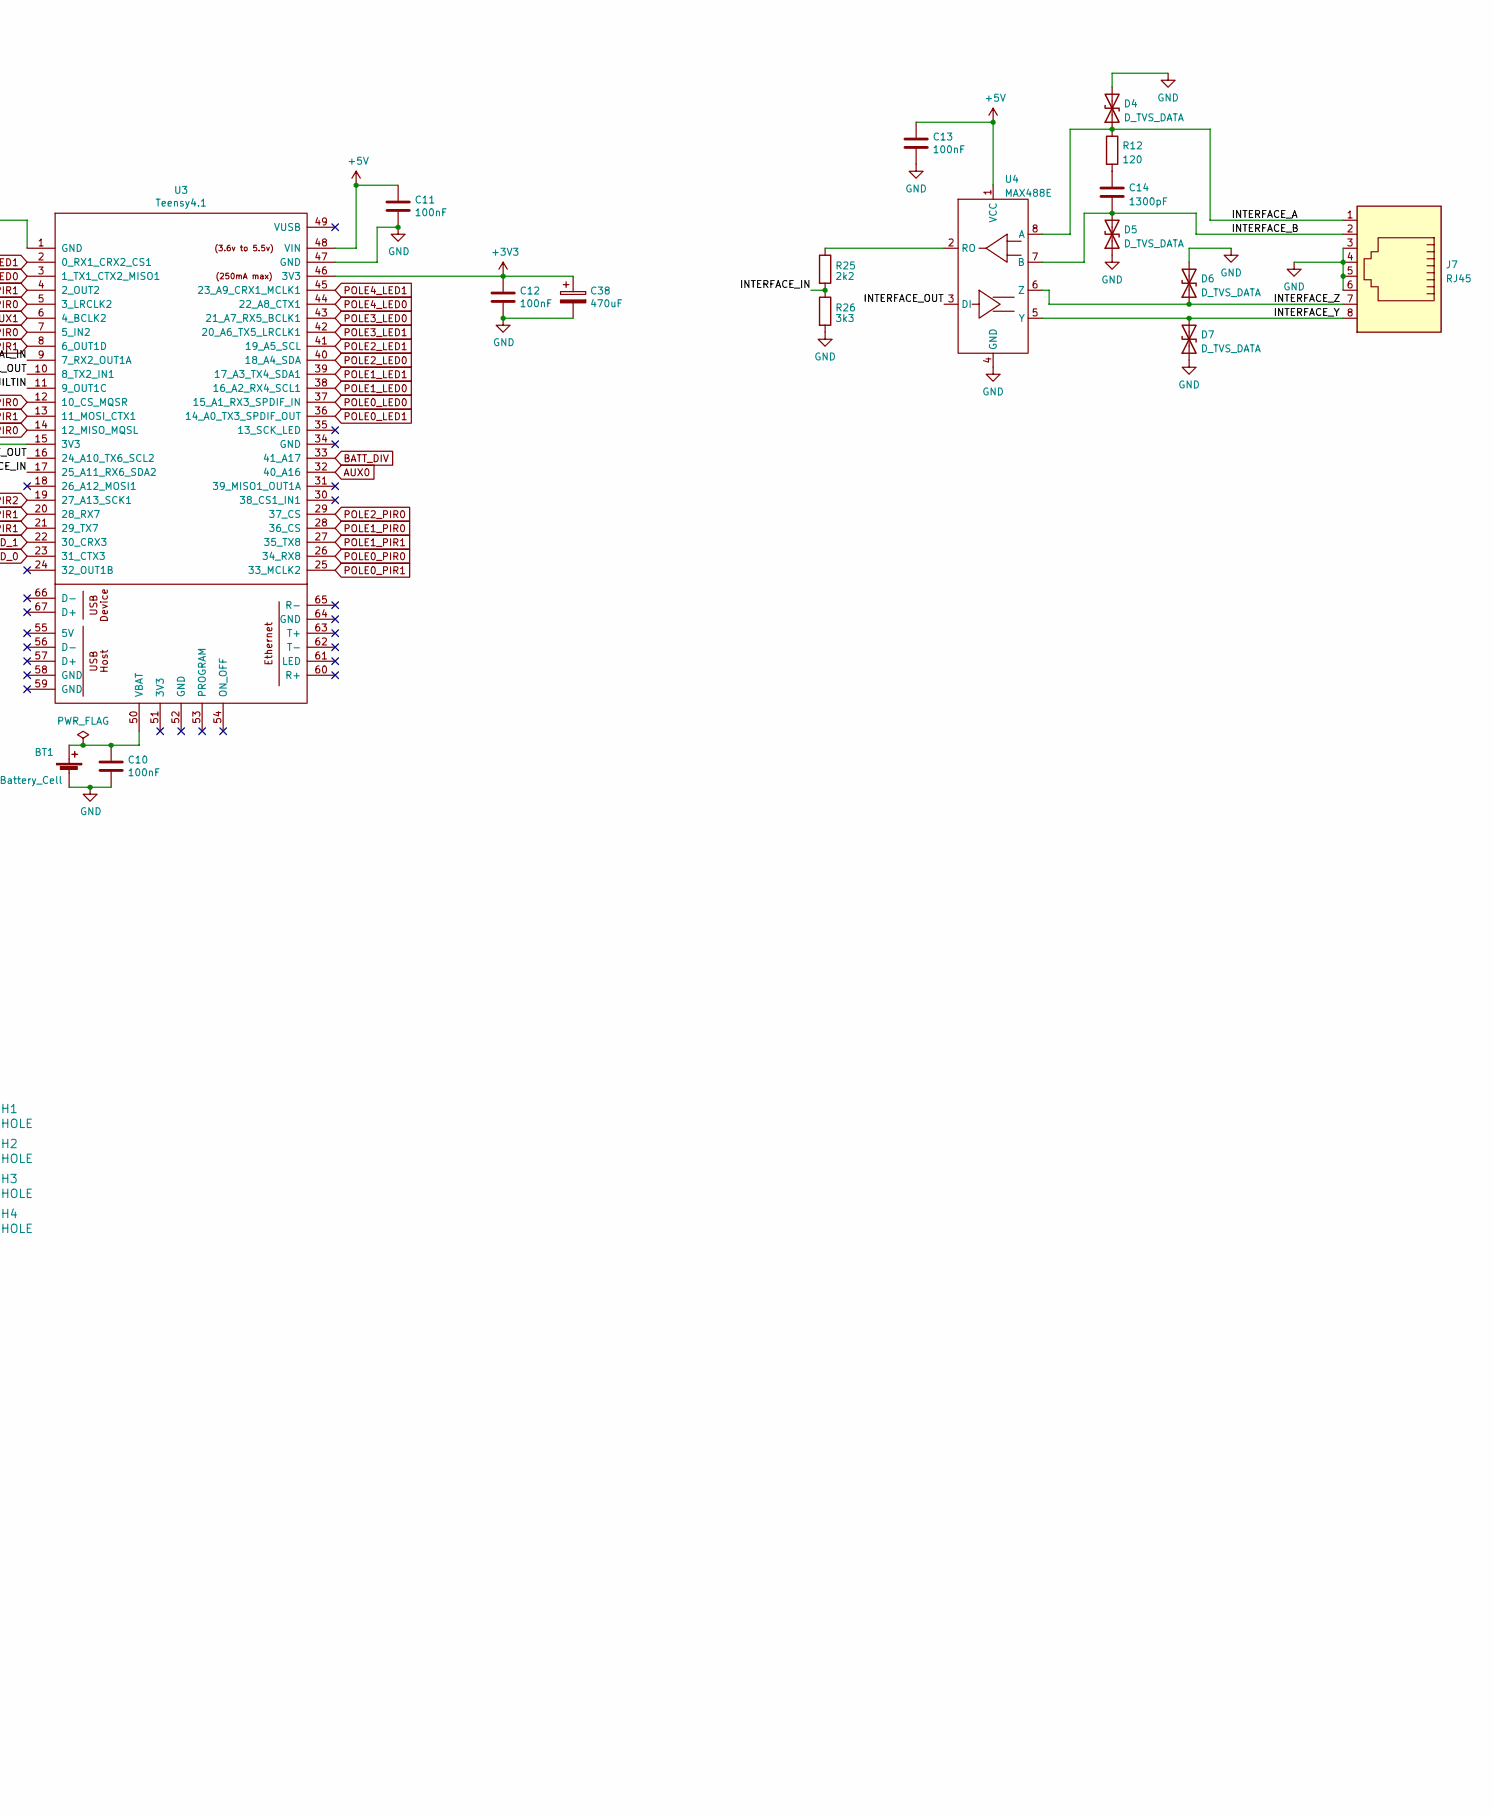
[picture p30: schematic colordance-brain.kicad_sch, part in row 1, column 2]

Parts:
BT1: Battery_Cell; BatteryHolder_Keystone_3034_1x20mm; MPN 3034
C1, C2, C3, C5, C6, C8, C9, C10, C11, C12, C13, C36: 100nF; C_0402_1005Metric; LCSC C307331
C4, C7, C37: 22nF; C_0603_1608Metric; LCSC C21122
C14: 1300pF; C_0603_1608Metric; LCSC C1595
C38: 470uF; CP_Radial_D10.0mm_P5.00mm; MPN ESC477M035AH4EA
D1: LED; LED_0603_1608Metric; MPN 150060RS75000; LCSC C2286
D2, D3: D_TVS_5V; D_SMB; MPN SMBJ6.0CD-M3/H; LCSC C78395
D4, D5, D6, D7: D_TVS_DATA; D_SMB; MPN SMBJ6.0CD-M3/H; LCSC C78395
H1, H2, H3, H4: HOLE; HOLE_5MM_#8
J1: Conn_01x04; PinHeader_1x04_P2.54mm_Horizontal
J2, J3, J4, J5, J15: Conn_01x03; PinHeader_1x03_P2.54mm_Horizontal; MPN 78208-103HLF
J6: Conn_01x05; PinHeader_1x05_P2.54mm_Horizontal
J7: RJ45; RJ45_Amphenol_54602-x08_Horizontal; MPN 54601-908WPLF
R1: 10k; R_0603_1608Metric; LCSC C25804
R2: 120k; R_0603_1608Metric; MPN RG2012P-125-B-T5; LCSC C25808
R3: 33k; R_0603_1608Metric; MPN RT0603BRD07330KL; LCSC C4216
R4, R5, R8, R11: 470; R_0603_1608Metric; LCSC C23179
R6, R7, R9, R10, R27: 1k; R_0603_1608Metric; LCSC C21190
R12: 120; R_0603_1608Metric; LCSC C22787
R25: 2k2; R_0603_1608Metric; LCSC C4190
R26: 3k3; R_0603_1608Metric; LCSC C22978
SW1: SW_SPST; SW_PUSH_6mm
U1, U2: 74AHCT1G126; SOT-23-5; MPN 74AHCT1G126SE-7; LCSC C163712
U3: Teensy4.1; Teensy41_stripped; MPN PPPC241LFBN-RC
U4: MAX488E; SOIC-8_3.9x4.9mm_P1.27mm; LCSC C10919

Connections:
+3V3: C9.1, C12.1, C38.1, J6.4, U3.15 (3V3), U3.46 (3V3)
+5V: C1.1, C2.1, C3.1, C6.1, C8.1, C11.1, C13.1, C36.1, D1.2 (A), J1.4, J2.3, J3.3, J4.3, J5.3, J6.5, J15.3, U1.1, U1.5 (VCC), U2.1, U2.5 (VCC), U3.48 (VIN), U4.1 (VCC); also elsewhere on the board
+12V: R2.1; also elsewhere on the board
/AUX_SERIAL_IN: D2.2 (A2), R4.1, U3.9 (7_RX2_OUT1A)
/AUX_SERIAL_OUT: D3.2 (A2), R8.1, U3.10 (8_TX2_IN1)
/INTERFACE_A: D4.1 (A1), J7.1, R12.1, U4.8 (A)
/INTERFACE_B: C14.2, D5.2 (A2), J7.2, U4.7 (B)
/INTERFACE_IN: R25.2, R26.1, U3.17 (25_A11_RX6_SDA2)
/INTERFACE_OUT: U3.16 (24_A10_TX6_SCL2), U4.3 (DI)
/INTERFACE_Y: D7.2 (A2), J7.8, U4.5 (Y)
/INTERFACE_Z: D6.1 (A1), J7.7, U4.6 (Z)
/SW_BUILTIN: SW1.2 (B), U3.11 (9_OUT1C)
AUX0: J6.2, U3.32 (40_A16)
AUX1: J6.3, U3.6 (4_BCLK2)
BATT_DIV: R7.1, U3.33 (41_A17)
GND: BT1.2 (-), C1.2, C2.2, C3.2, C4.2, C5.2, C6.2, C7.2, C8.2, C9.2, C10.2, C11.2, C12.2, C13.2, C36.2, C37.2, C38.2, D2.1 (A1), D3.1 (A1), D4.2 (A2), D5.1 (A1), D6.2 (A2), D7.1 (A1), J1.1, J2.1, J3.1, J4.1, J5.1, J6.1, J7.3, J7.4, J7.5, J7.6, J15.1, R1.2, R3.2, R9.2, R26.2, U1.3 (GND), U2.3 (GND), U3.1 (GND), U3.47 (GND), U4.4 (GND); also elsewhere on the board
LOCAL_LED_0: U1.2, U3.23 (31_CTX3)
LOCAL_LED_1: U2.2, U3.22 (30_CRX3)
LOCAL_PIR0: C4.1, R6.1, U3.5 (3_LRCLK2)
LOCAL_PIR1: C7.1, R10.1, U3.4 (2_OUT2)
LOCAL_PIR2: C37.1, R27.1, U3.19 (27_A13_SCK1)
unnamed: BT1.1 (+), C10.1, U3.50 (VBAT)
unnamed: C5.1, R2.2, R3.1, R7.2
unnamed: C14.1, R12.2
unnamed: D1.1 (K), R1.1
unnamed: J1.2, R4.2
unnamed: J1.3, R8.2
unnamed: J2.2, R5.2
unnamed: J3.2, R6.2
unnamed: J4.2, R10.2
unnamed: J5.2, R11.2
unnamed: J15.2, R27.2
unnamed: R5.1, U1.4
unnamed: R11.1, U2.4
unnamed: R9.1, SW1.1 (A)
unnamed: R25.1, U4.2 (RO)
POLE0_LED0: U3.37 (15_A1_RX3_SPDIF_IN); also elsewhere on the board
POLE0_LED1: U3.36 (14_A0_TX3_SPDIF_OUT); also elsewhere on the board
POLE0_PIR0: U3.26 (34_RX8); also elsewhere on the board
POLE0_PIR1: U3.25 (33_MCLK2); also elsewhere on the board
POLE1_LED0: U3.38 (16_A2_RX4_SCL1); also elsewhere on the board
POLE1_LED1: U3.39 (17_A3_TX4_SDA1); also elsewhere on the board
POLE1_PIR0: U3.28 (36_CS); also elsewhere on the board
POLE1_PIR1: U3.27 (35_TX8); also elsewhere on the board
POLE2_LED0: U3.40 (18_A4_SDA); also elsewhere on the board
POLE2_LED1: U3.41 (19_A5_SCL); also elsewhere on the board
POLE2_PIR0: U3.29 (37_CS); also elsewhere on the board
POLE2_PIR1: U3.21 (29_TX7); also elsewhere on the board
POLE3_LED0: U3.43 (21_A7_RX5_BCLK1); also elsewhere on the board
POLE3_LED1: U3.42 (20_A6_TX5_LRCLK1); also elsewhere on the board
POLE3_PIR0: U3.14 (12_MISO_MQSL); also elsewhere on the board
POLE3_PIR1: U3.20 (28_RX7); also elsewhere on the board
POLE4_LED0: U3.44 (22_A8_CTX1); also elsewhere on the board
POLE4_LED1: U3.45 (23_A9_CRX1_MCLK1); also elsewhere on the board
POLE4_PIR0: U3.12 (10_CS_MQSR); also elsewhere on the board
POLE4_PIR1: U3.13 (11_MOSI_CTX1); also elsewhere on the board
POLE5_LED0: U3.3 (1_TX1_CTX2_MISO1); also elsewhere on the board
POLE5_LED1: U3.2 (0_RX1_CRX2_CS1); also elsewhere on the board
POLE5_PIR0: U3.7 (5_IN2); also elsewhere on the board
POLE5_PIR1: U3.8 (6_OUT1D); also elsewhere on the board

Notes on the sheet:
Local LEDs
Out To Poles
Local PIR

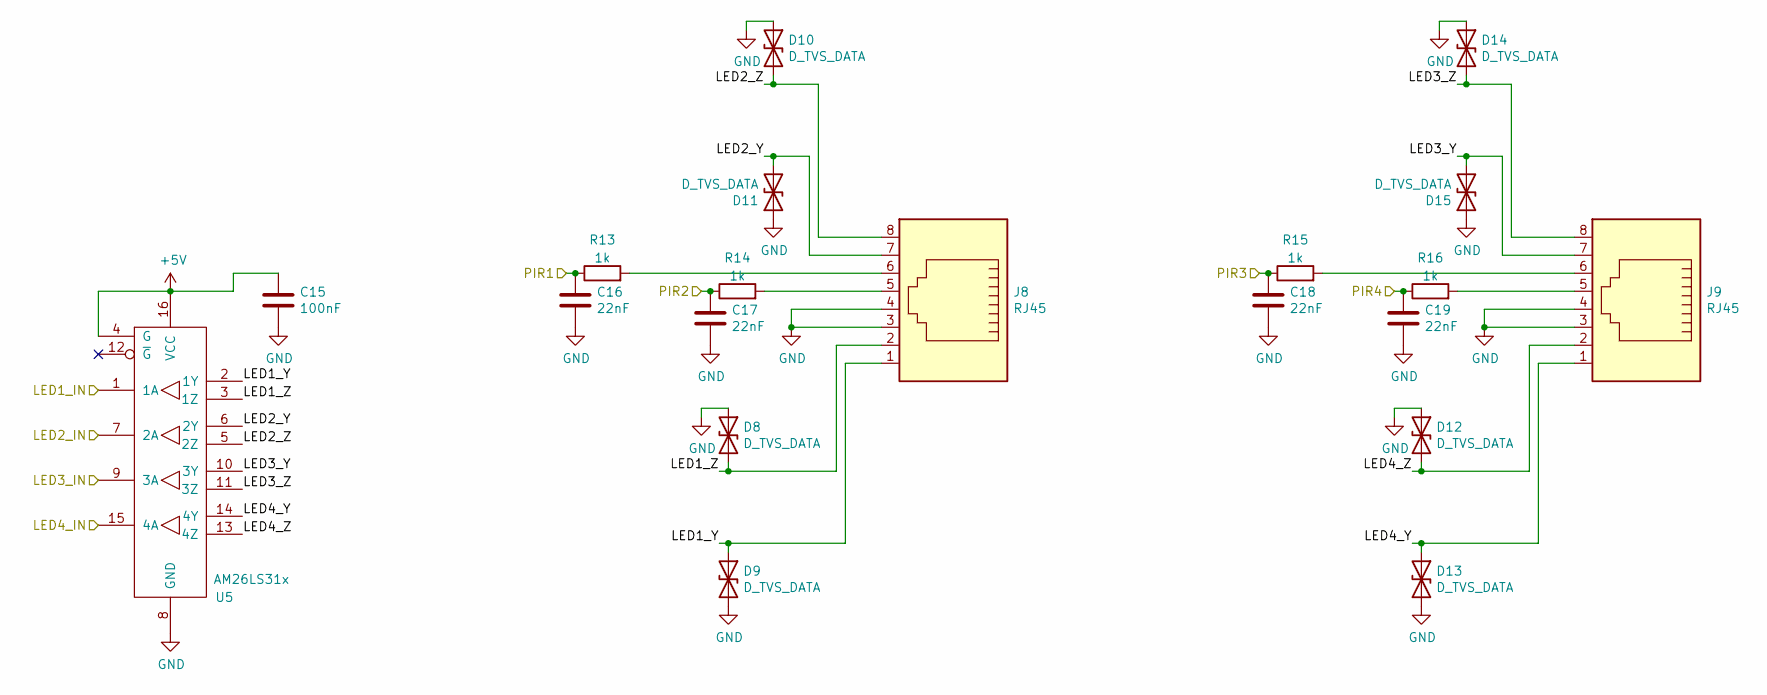
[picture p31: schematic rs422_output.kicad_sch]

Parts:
C15: 100nF; C_0402_1005Metric; LCSC C307331
C16, C17, C18, C19: 22nF; C_0603_1608Metric; LCSC C21122
D8, D9, D10, D11, D12, D13, D14, D15: D_TVS_DATA; D_SMB; MPN SMBJ6.0CD-M3/H; LCSC C78395
J8, J9: RJ45; RJ45_Amphenol_54602-x08_Horizontal; MPN 54601-908WPLF
R13, R14, R15, R16: 1k; R_0603_1608Metric; LCSC C21190
U5: AM26LS31x; SOIC-16_3.9x9.9mm_P1.27mm; MPN AM26LS31CDR; LCSC C6179

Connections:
+5V: C15.1, U5.4 (G), U5.16 (VCC); also elsewhere on the board
/rs422_output/LED1_Y: D9.1 (A1), J8.1, U5.2 (1Y)
/rs422_output/LED1_Z: D8.2 (A2), J8.2, U5.3 (1Z)
/rs422_output/LED2_Y: D11.2 (A2), J8.7, U5.6 (2Y)
/rs422_output/LED2_Z: D10.2 (A2), J8.8, U5.5 (2Z)
/rs422_output/LED3_Y: D15.2 (A2), J9.7, U5.10 (3Y)
/rs422_output/LED3_Z: D14.2 (A2), J9.8, U5.11 (3Z)
/rs422_output/LED4_Y: D13.1 (A1), J9.1, U5.14 (4Y)
/rs422_output/LED4_Z: D12.2 (A2), J9.2, U5.13 (4Z)
GND: C15.2, C16.2, C17.2, C18.2, C19.2, D8.1 (A1), D9.2 (A2), D10.1 (A1), D11.1 (A1), D12.1 (A1), D13.2 (A2), D14.1 (A1), D15.1 (A1), J8.3, J8.4, J9.3, J9.4, U5.8 (GND); also elsewhere on the board
unnamed: J8.5, R14.2
unnamed: J8.6, R13.2
unnamed: J9.5, R16.2
unnamed: J9.6, R15.2
POLE0_LED0: U5.9 (3A); also elsewhere on the board
POLE0_LED1: U5.15 (4A); also elsewhere on the board
POLE0_PIR0: C18.1, R15.1; also elsewhere on the board
POLE0_PIR1: C19.1, R16.1; also elsewhere on the board
POLE1_LED0: U5.1 (1A); also elsewhere on the board
POLE1_LED1: U5.7 (2A); also elsewhere on the board
POLE1_PIR0: C16.1, R13.1; also elsewhere on the board
POLE1_PIR1: C17.1, R14.1; also elsewhere on the board

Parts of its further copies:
C20, C25: 100nF; C_0402_1005Metric; LCSC C307331
C21, C22, C23, C24, C26, C27, C28, C29: 22nF; C_0603_1608Metric; LCSC C21122
D16, D17, D18, D19, D20, D21, D22, D23, D24, D25, D26, D27, D28, D29, D30, D31: D_TVS_DATA; D_SMB; MPN SMBJ6.0CD-M3/H; LCSC C78395
J10, J11, J12, J13: RJ45; RJ45_Amphenol_54602-x08_Horizontal; MPN 54601-908WPLF
R17, R18, R19, R20, R21, R22, R23, R24: 1k; R_0603_1608Metric; LCSC C21190
U6, U7: AM26LS31x; SOIC-16_3.9x9.9mm_P1.27mm; MPN AM26LS31CDR; LCSC C6179

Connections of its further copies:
+5V: C20.1, C25.1, U6.4 (G), U6.16 (VCC), U7.4 (G), U7.16 (VCC); also elsewhere on the board
/sheet6087EBF5/LED1_Y: D17.1 (A1), J10.1, U6.2 (1Y)
/sheet6087EBF5/LED1_Z: D16.2 (A2), J10.2, U6.3 (1Z)
/sheet6087EBF5/LED2_Y: D19.2 (A2), J10.7, U6.6 (2Y)
/sheet6087EBF5/LED2_Z: D18.2 (A2), J10.8, U6.5 (2Z)
/sheet6087EBF5/LED3_Y: D23.2 (A2), J11.7, U6.10 (3Y)
/sheet6087EBF5/LED3_Z: D22.2 (A2), J11.8, U6.11 (3Z)
/sheet6087EBF5/LED4_Y: D21.1 (A1), J11.1, U6.14 (4Y)
/sheet6087EBF5/LED4_Z: D20.2 (A2), J11.2, U6.13 (4Z)
/sheet6087FA83/LED1_Y: D25.1 (A1), J12.1, U7.2 (1Y)
/sheet6087FA83/LED1_Z: D24.2 (A2), J12.2, U7.3 (1Z)
/sheet6087FA83/LED2_Y: D27.2 (A2), J12.7, U7.6 (2Y)
/sheet6087FA83/LED2_Z: D26.2 (A2), J12.8, U7.5 (2Z)
/sheet6087FA83/LED3_Y: D31.2 (A2), J13.7, U7.10 (3Y)
/sheet6087FA83/LED3_Z: D30.2 (A2), J13.8, U7.11 (3Z)
/sheet6087FA83/LED4_Y: D29.1 (A1), J13.1, U7.14 (4Y)
/sheet6087FA83/LED4_Z: D28.2 (A2), J13.2, U7.13 (4Z)
GND: C20.2, C21.2, C22.2, C23.2, C24.2, C25.2, C26.2, C27.2, C28.2, C29.2, D16.1 (A1), D17.2 (A2), D18.1 (A1), D19.1 (A1), D20.1 (A1), D21.2 (A2), D22.1 (A1), D23.1 (A1), D24.1 (A1), D25.2 (A2), D26.1 (A1), D27.1 (A1), D28.1 (A1), D29.2 (A2), D30.1 (A1), D31.1 (A1), J10.3, J10.4, J11.3, J11.4, J12.3, J12.4, J13.3, J13.4, U6.8 (GND), U7.8 (GND); also elsewhere on the board
unnamed: J10.5, R18.2
unnamed: J10.6, R17.2
unnamed: J11.5, R20.2
unnamed: J11.6, R19.2
unnamed: J12.5, R22.2
unnamed: J12.6, R21.2
unnamed: J13.5, R24.2
unnamed: J13.6, R23.2
POLE2_LED0: U7.1 (1A); also elsewhere on the board
POLE2_LED1: U7.7 (2A); also elsewhere on the board
POLE2_PIR0: C26.1, R21.1; also elsewhere on the board
POLE2_PIR1: C27.1, R22.1; also elsewhere on the board
POLE3_LED0: U7.9 (3A); also elsewhere on the board
POLE3_LED1: U7.15 (4A); also elsewhere on the board
POLE3_PIR0: C28.1, R23.1; also elsewhere on the board
POLE3_PIR1: C29.1, R24.1; also elsewhere on the board
POLE4_LED0: U6.9 (3A); also elsewhere on the board
POLE4_LED1: U6.15 (4A); also elsewhere on the board
POLE4_PIR0: C23.1, R19.1; also elsewhere on the board
POLE4_PIR1: C24.1, R20.1; also elsewhere on the board
POLE5_LED0: U6.1 (1A); also elsewhere on the board
POLE5_LED1: U6.7 (2A); also elsewhere on the board
POLE5_PIR0: C21.1, R17.1; also elsewhere on the board
POLE5_PIR1: C22.1, R18.1; also elsewhere on the board

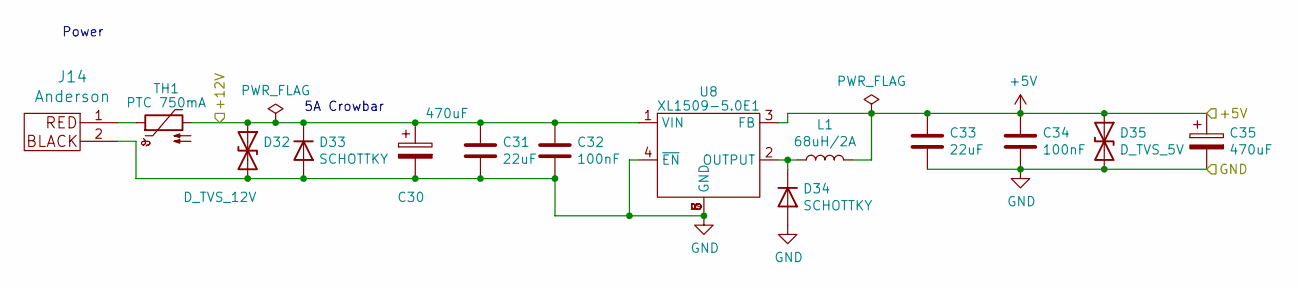
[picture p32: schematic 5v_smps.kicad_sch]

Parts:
C30, C35: 470uF; CP_Radial_D10.0mm_P5.00mm; MPN ESC477M035AH4EA
C31, C33: 22uF; C_0805_2012Metric; MPN LMK212BBJ226MG-T; LCSC C45783
C32, C34: 100nF; C_0402_1005Metric; LCSC C307331
D32: D_TVS_12V; D_SMB; MPN SMBJ13CA; LCSC C1976713
D33, D34: SCHOTTKY; D_SMA; LCSC C22452
D35: D_TVS_5V; D_SMB; MPN SMBJ6.0CD-M3/H; LCSC C78395
J14: Anderson; Anderson_1336G1_right_angle_bottom_two
L1: 68uH/2A; L_PROD-Tech_PSPMAA0805; LCSC C2962891
TH1: PTC 750mA; Fuse_1812_4532Metric; LCSC C20997
U8: XL1509-5.0E1; SOIC-8_3.9x4.9mm_P1.27mm; LCSC C61063

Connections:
+5V: C33.1, C34.1, C35.1, D35.1 (A1), L1.2, U8.3 (FB); also elsewhere on the board
+12V: C30.1, C31.1, C32.1, D32.1 (A1), D33.1 (K), TH1.2, U8.1 (VIN); also elsewhere on the board
GND: C30.2, C31.2, C32.2, C33.2, C34.2, C35.2, D32.2 (A2), D33.2 (A), D34.2 (A), D35.2 (A2), J14.2, U8.4 (~EN), U8.5 (GND), U8.6 (GND), U8.7 (GND), U8.8 (GND); also elsewhere on the board
unnamed: D34.1 (K), L1.1, U8.2 (OUTPUT)
unnamed: J14.1, TH1.1

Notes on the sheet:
Power
5A Crowbar

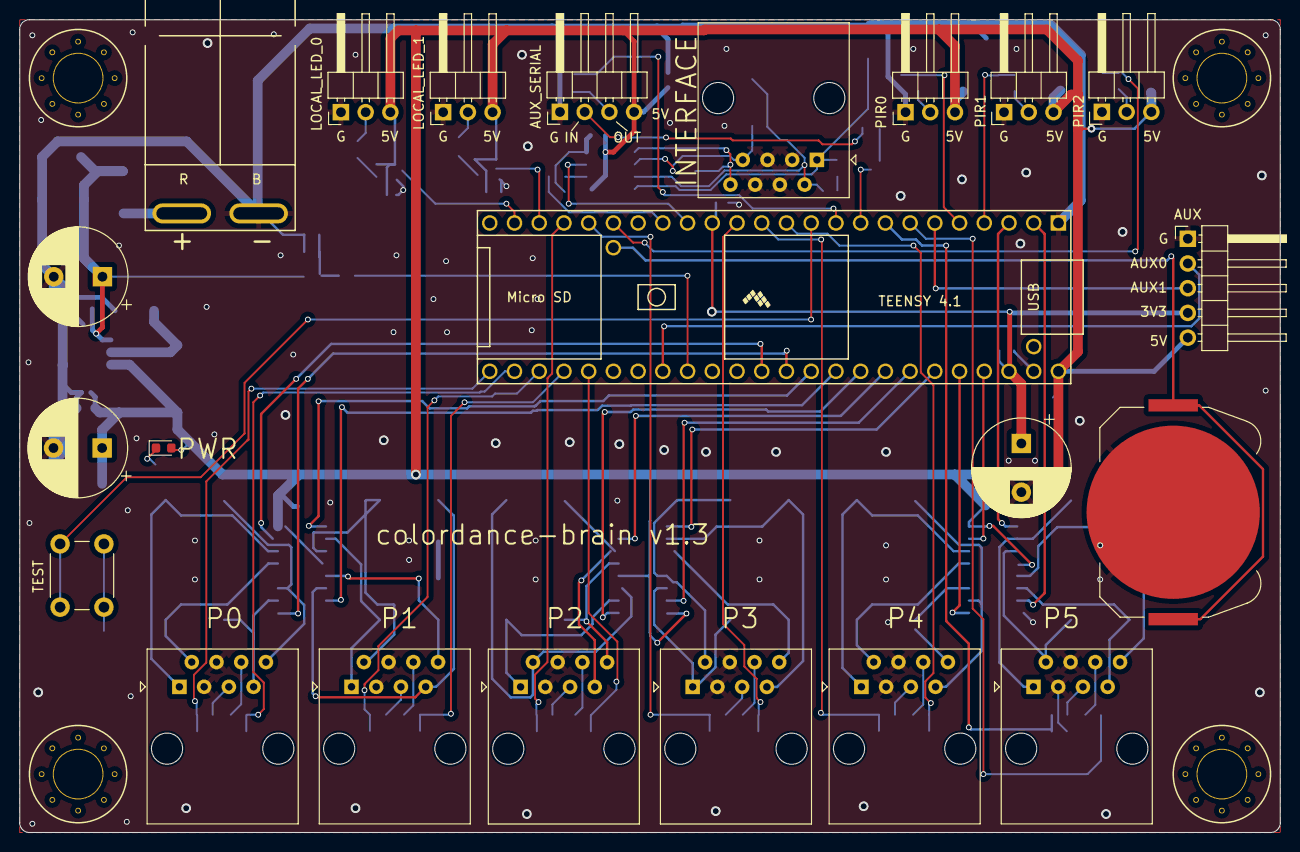
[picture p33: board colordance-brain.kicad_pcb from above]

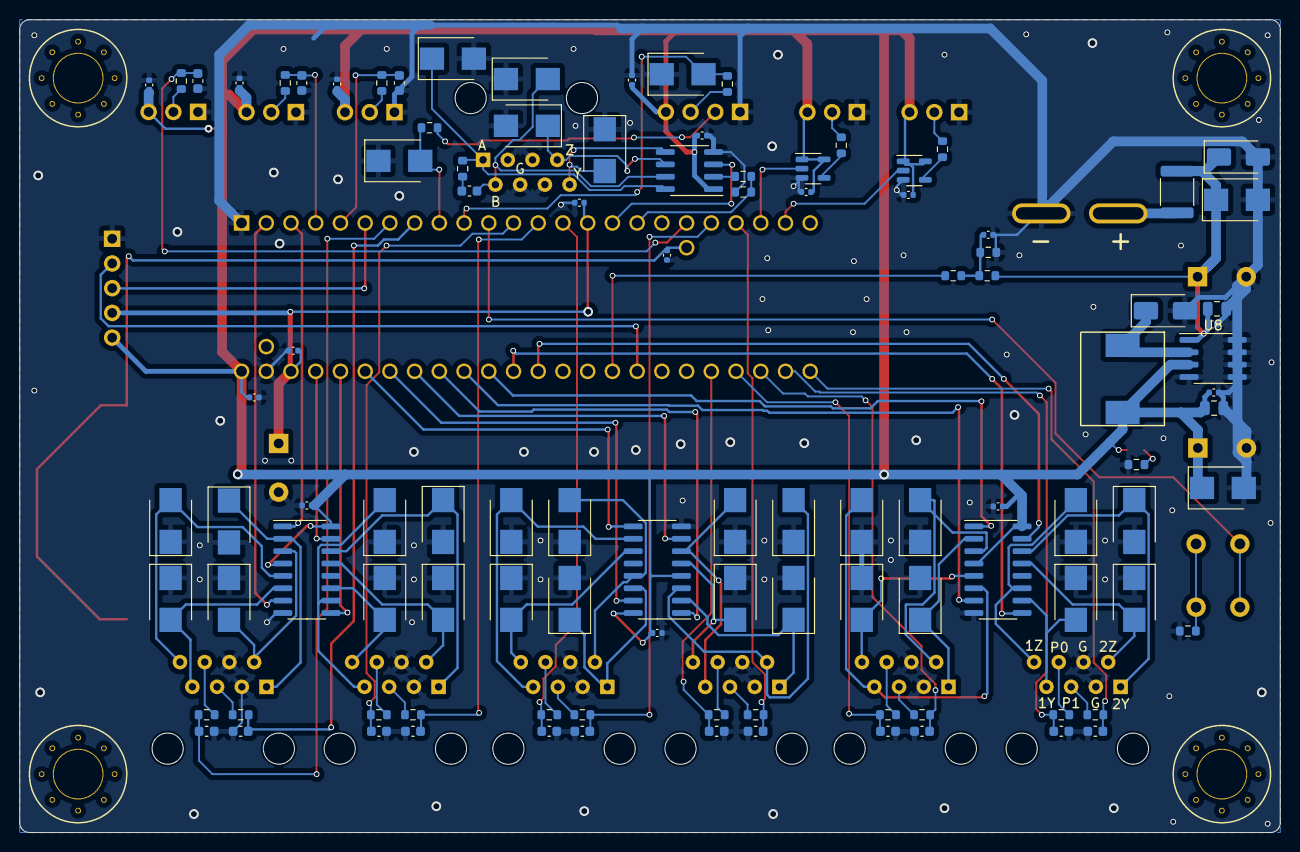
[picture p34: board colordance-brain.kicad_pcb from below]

Board: 2 copper layers, 129.5 x 83.5 mm, 131 parts (105 on the bottom side), 98 nets.

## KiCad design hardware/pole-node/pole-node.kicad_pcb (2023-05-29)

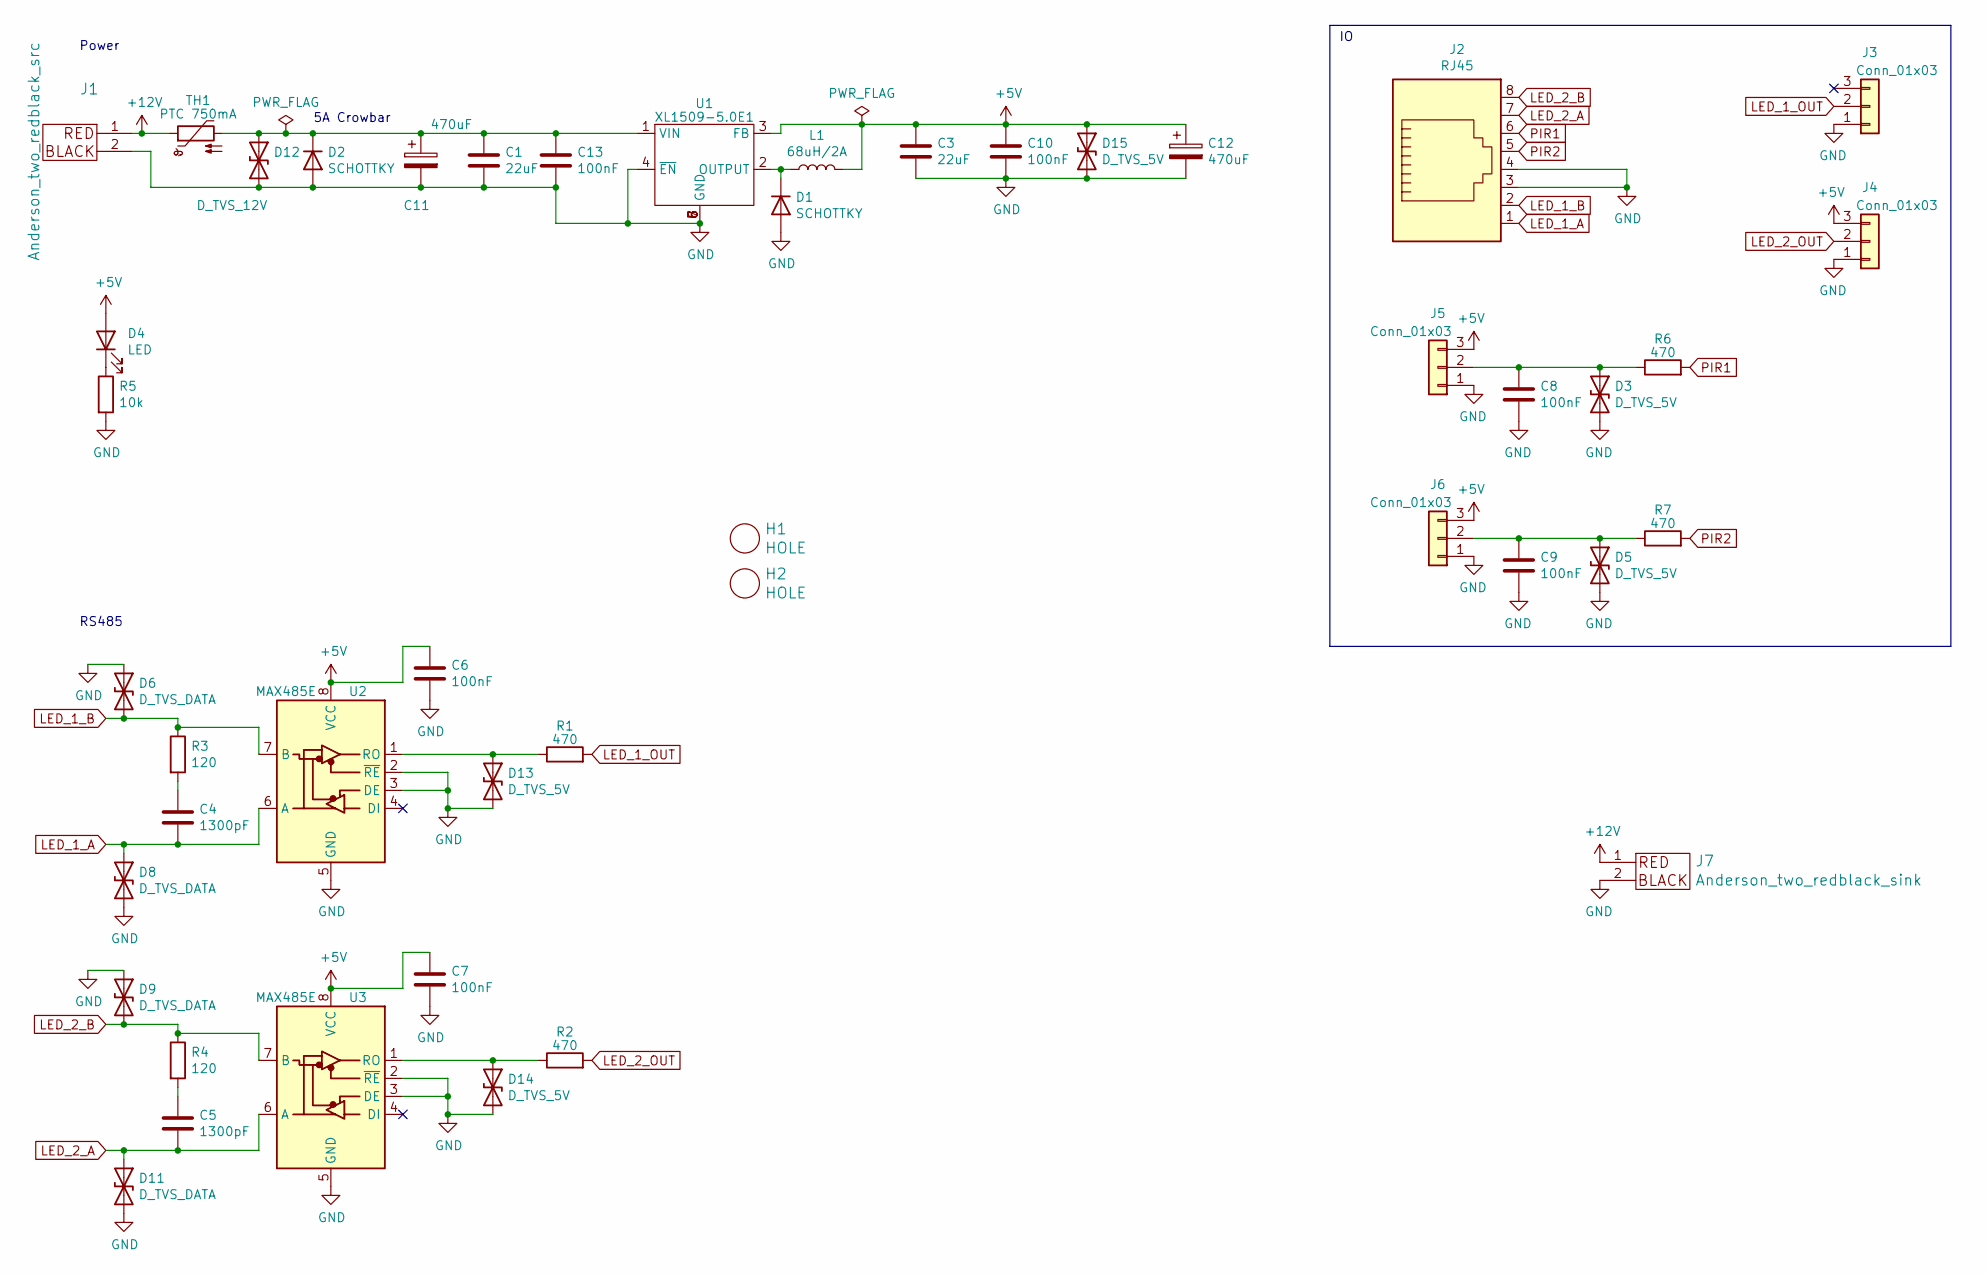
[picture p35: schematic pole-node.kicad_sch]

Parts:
C1, C3: 22uF; C_0805_2012Metric; MPN LMK212BBJ226MG-T; LCSC C45783
C4, C5: 1300pF; C_0603_1608Metric; MPN CL10B122KB8NNNC; LCSC C1595
C6, C7, C8, C9, C10, C13: 100nF; C_0402_1005Metric; LCSC C307331
C11, C12: 470uF; CP_Radial_D10.0mm_P5.00mm; MPN ESC477M035AH4EA
D1, D2: SCHOTTKY; D_SMA; LCSC C22452
D3, D5, D13, D14, D15: D_TVS_5V; D_SMB; MPN SMBJ6.0CD-M3/H; LCSC C78395
D4: LED; LED_0603_1608Metric; MPN 150060RS75000; LCSC C2286
D6, D8, D9, D11: D_TVS_DATA; D_SMB; MPN SMBJ6.0CD-M3/H; LCSC C78395
D12: D_TVS_12V; D_SMB; MPN SMBJ13CA; LCSC C1976713
H1, H2: HOLE
J1: Anderson_two_redblack_src
J2: RJ45; RJ45_Amphenol_54602-x08_Horizontal; MPN 54601-908WPLF
J3, J4, J5, J6: Conn_01x03; PinHeader_1x03_P2.54mm_Horizontal; MPN 78208-103HLF
J7: Anderson_two_redblack_sink
L1: 68uH/2A; L_PROD-Tech_PSPMAA0805; LCSC C2962891
R1, R2, R6, R7: 470; R_0603_1608Metric; LCSC C23179
R3, R4: 120; R_0603_1608Metric; MPN RMCF0603JG120R; LCSC C22787
R5: 10k; R_0603_1608Metric; LCSC C25804
TH1: PTC 750mA; Fuse_1812_4532Metric; LCSC C20997
U1: XL1509-5.0E1; SOIC-8_3.9x4.9mm_P1.27mm; LCSC C61063
U2, U3: MAX485E; SOIC-8_3.9x4.9mm_P1.27mm; MPN SP485ECN-L/TR; LCSC C916163

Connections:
+5V: C3.1, C6.1, C7.1, C10.1, C12.1, D4.2 (A), D15.1 (A1), J4.3, J5.3, J6.3, L1.2, U1.3 (FB), U2.8 (VCC), U3.8 (VCC)
+12V: J1.1, J7.1, TH1.1
GND: C1.2, C3.2, C6.2, C7.2, C8.2, C9.2, C10.2, C11.2, C12.2, C13.2, D1.2 (A), D2.2 (A), D3.2 (A2), D5.2 (A2), D6.1 (A1), D8.2 (A2), D9.1 (A1), D11.2 (A2), D12.2 (A2), D13.2 (A2), D14.2 (A2), D15.2 (A2), J1.2, J2.3, J2.4, J3.1, J4.1, J5.1, J6.1, J7.2, R5.2, U1.4 (~EN), U1.5 (GND), U1.6 (GND), U1.7 (GND), U1.8 (GND), U2.2 (~RE), U2.3 (DE), U2.5 (GND), U3.2 (~RE), U3.3 (DE), U3.5 (GND)
LED_1_A: C4.2, D8.1 (A1), J2.1, U2.6 (A)
LED_1_B: D6.2 (A2), J2.2, R3.1, U2.7 (B)
LED_1_OUT: J3.2, R1.2
LED_2_A: C5.2, D11.1 (A1), J2.7, U3.6 (A)
LED_2_B: D9.2 (A2), J2.8, R4.1, U3.7 (B)
LED_2_OUT: J4.2, R2.2
unnamed: C1.1, C11.1, C13.1, D2.1 (K), D12.1 (A1), TH1.2, U1.1 (VIN)
unnamed: C4.1, R3.2
unnamed: C5.1, R4.2
unnamed: D1.1 (K), L1.1, U1.2 (OUTPUT)
unnamed: C8.1, D3.1 (A1), J5.2, R6.1
unnamed: D4.1 (K), R5.1
unnamed: C9.1, D5.1 (A1), J6.2, R7.1
unnamed: D13.1 (A1), R1.1, U2.1 (RO)
unnamed: D14.1 (A1), R2.1, U3.1 (RO)
PIR1: J2.6, R6.2
PIR2: J2.5, R7.2

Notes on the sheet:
Power
5A Crowbar
RS485

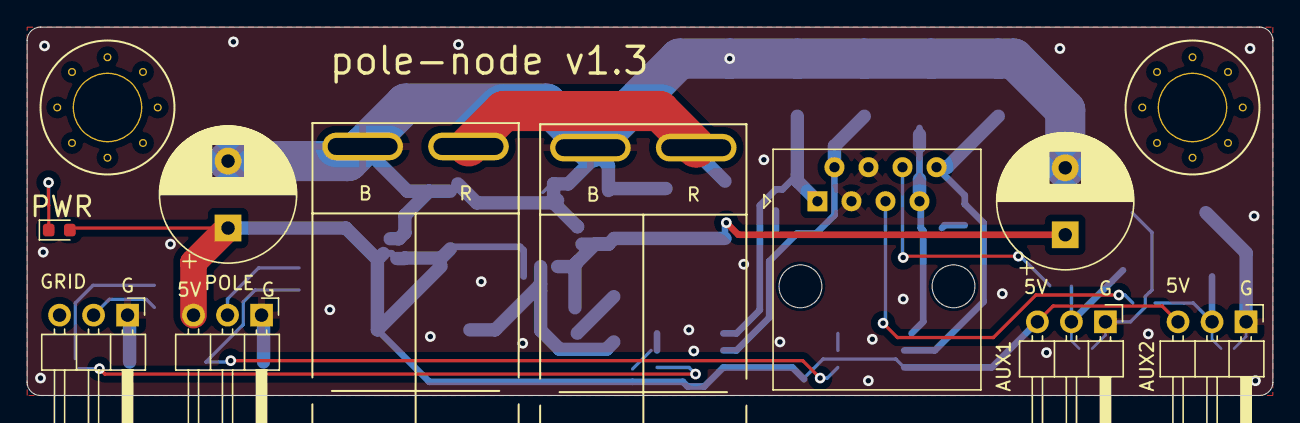
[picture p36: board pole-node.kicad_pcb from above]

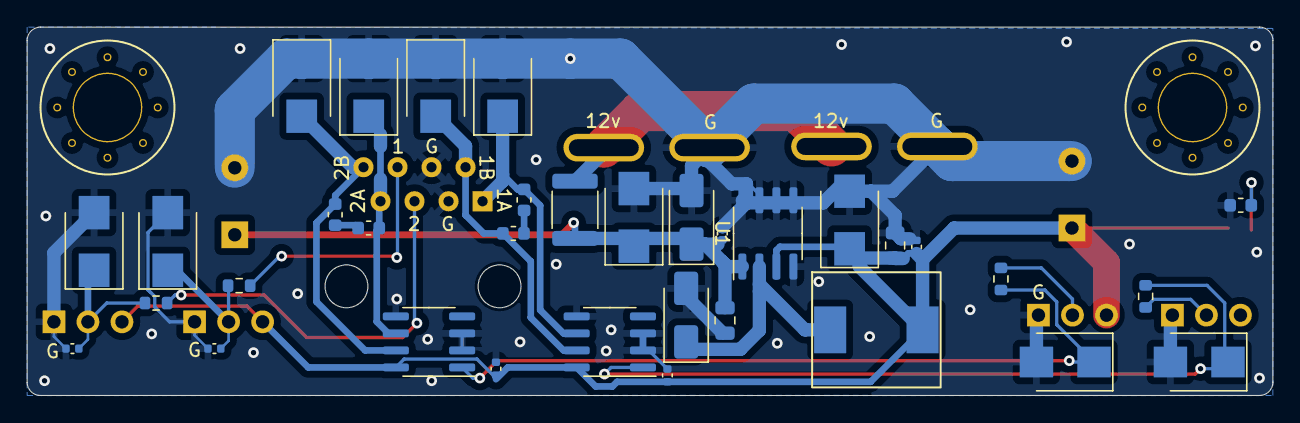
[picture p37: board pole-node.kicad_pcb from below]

Board: 2 copper layers, 93.0 x 27.5 mm, 46 parts (34 on the bottom side), 20 nets.

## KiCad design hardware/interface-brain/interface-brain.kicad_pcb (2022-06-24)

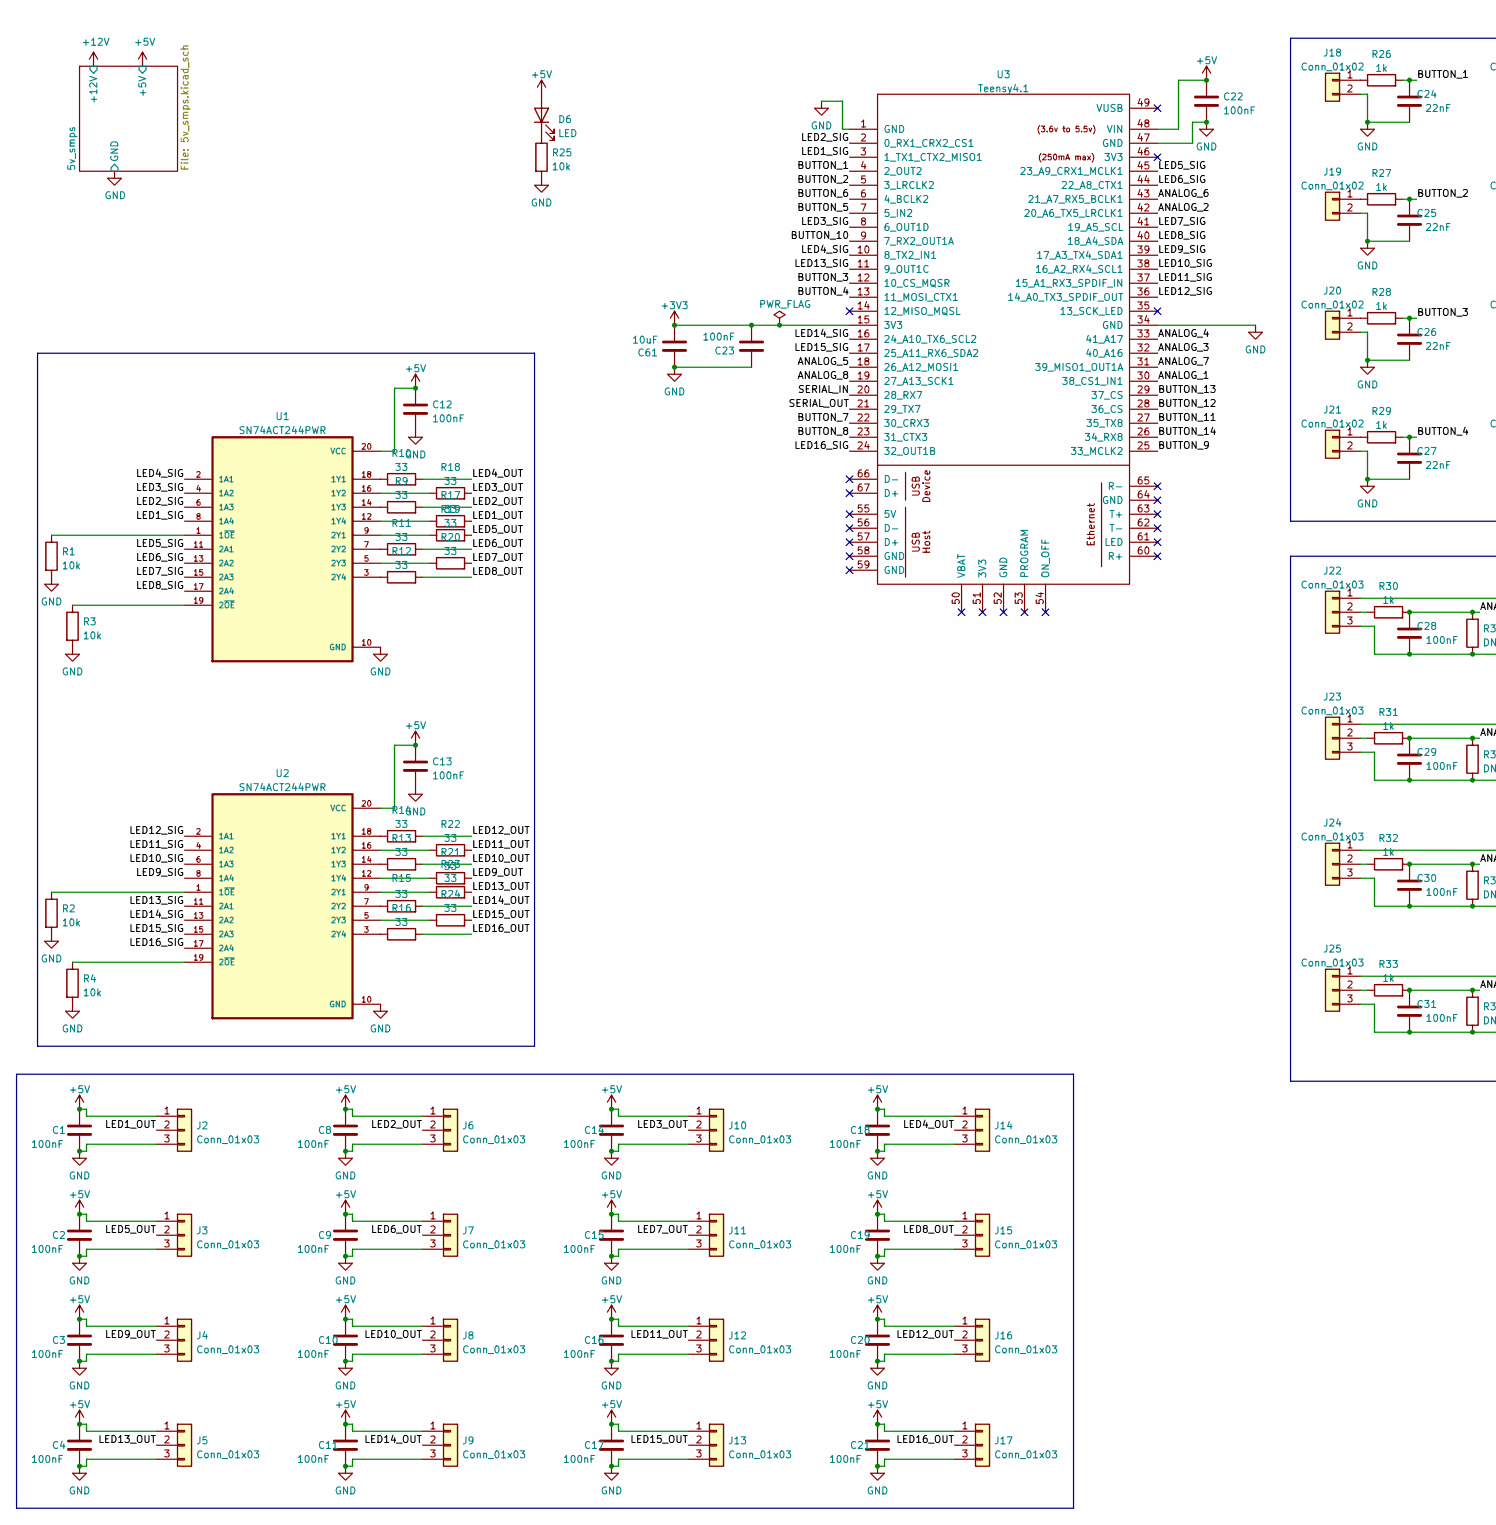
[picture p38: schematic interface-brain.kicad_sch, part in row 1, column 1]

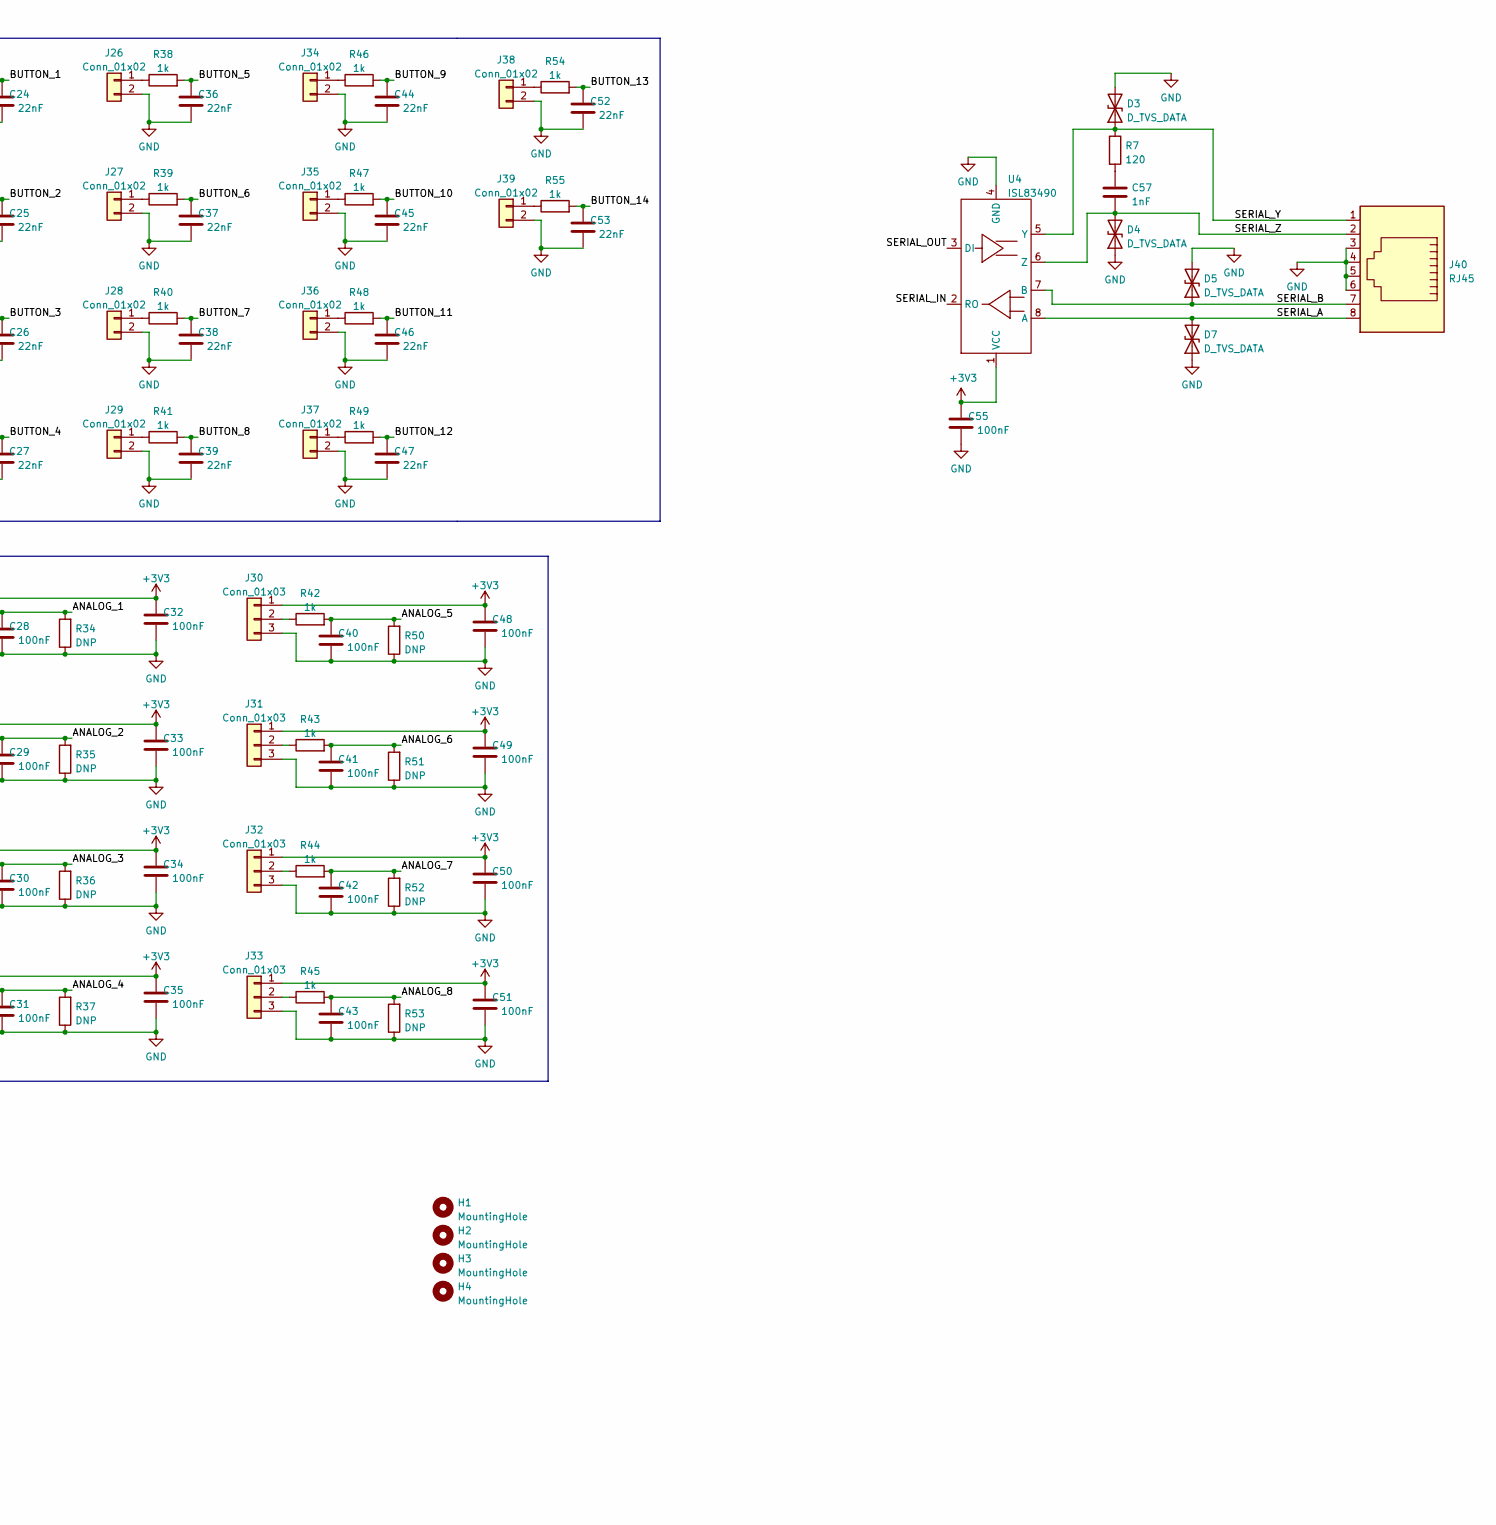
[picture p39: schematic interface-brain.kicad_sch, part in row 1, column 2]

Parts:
C1, C2, C3, C4, C8, C9, C10, C11, C12, C13, C14, C15, C16, C17, C18, C19, C20, C21, C22, C23, C28, C29, C30, C31, C32, C33, C34, C35, C40, C41, C42, C43, C48, C49, C50, C51, C55: 100nF; C_0402_1005Metric; LCSC C307331
C24, C25, C26, C27, C36, C37, C38, C39, C44, C45, C46, C47, C52, C53: 22nF; C_0402_1005Metric; LCSC C1532
C57: 1nF; C_0402_1005Metric; LCSC C1523
C61: 10uF; C_0805_2012Metric; LCSC C15850
D3, D4, D5, D7: D_TVS_DATA; D_SMB; MPN SMBJ6.0CD-M3/H
D6: LED; LED_0603_1608Metric; LCSC C2286
H1, H2, H3, H4: MountingHole; MountingHole_3.2mm_M3
J2, J3, J4, J5, J6, J7, J8, J9, J10, J11, J12, J13, J14, J15, J16, J17, J22, J23, J24, J25, J30, J31, J32, J33: Conn_01x03; MiniPV_69167-X03XXX_1x03_P2.54mm_Polarized_Vertical; MPN 69167-103HLF
J18, J19, J20, J21, J26, J27, J28, J29, J34, J35, J36, J37, J38, J39: Conn_01x02; MiniPV_76384-X02XX_1x02_P2.54mm_Vertical; MPN 76384-302LF
J40: RJ45; RJ45_Amphenol_54602-x08_Horizontal; MPN 54601-908WPLF
R1, R2, R3, R4, R25: 10k; R_0603_1608Metric; LCSC C25804
R7: 120; R_0603_1608Metric; LCSC C22787
R9, R10, R11, R12, R13, R14, R15, R16, R17, R18, R19, R20, R21, R22, R23, R24: 33; R_0603_1608Metric; LCSC C23140
R26, R27, R28, R29, R30, R31, R32, R33, R38, R39, R40, R41, R42, R43, R44, R45, R46, R47, R48, R49, R54, R55: 1k; R_0603_1608Metric; LCSC C21190
R34, R35, R36, R37, R50, R51, R52, R53: DNP; R_0603_1608Metric
U1, U2: SN74ACT244PWR; TSSOP-20_4.4x6.5mm_P0.65mm; LCSC C6930
U3: Teensy4.1; Teensy41_stripped; MPN PPPC241LFBN-RC
U4: ISL83490; SOIC-8_3.9x4.9mm_P1.27mm; MPN ISL83490IBZ-T

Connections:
+3V3: C23.2, C32.1, C33.1, C34.1, C35.1, C48.1, C49.1, C50.1, C51.1, C55.1, C61.2, J22.1, J23.1, J24.1, J25.1, J30.1, J31.1, J32.1, J33.1, U3.15 (3V3), U4.1 (VCC)
+5V: C1.2, C2.2, C3.2, C4.2, C8.2, C9.2, C10.2, C11.2, C12.1, C13.1, C14.2, C15.2, C16.2, C17.2, C18.2, C19.2, C20.2, C21.2, C22.1, D6.2 (A), J2.1, J3.1, J4.1, J5.1, J6.1, J7.1, J8.1, J9.1, J10.1, J11.1, J12.1, J13.1, J14.1, J15.1, J16.1, J17.1, U1.20 (VCC), U2.20 (VCC), U3.48 (VIN); also elsewhere on the board
/ANALOG_1: C28.1, R30.2, R34.2, U3.30 (38_CS1_IN1)
/ANALOG_2: C29.1, R31.2, R35.2, U3.42 (20_A6_TX5_LRCLK1)
/ANALOG_3: C30.1, R32.2, R36.2, U3.32 (40_A16)
/ANALOG_4: C31.1, R33.2, R37.2, U3.33 (41_A17)
/ANALOG_5: C40.1, R42.2, R50.2, U3.18 (26_A12_MOSI1)
/ANALOG_6: C41.1, R43.2, R51.2, U3.43 (21_A7_RX5_BCLK1)
/ANALOG_7: C42.1, R44.2, R52.2, U3.31 (39_MISO1_OUT1A)
/ANALOG_8: C43.1, R45.2, R53.2, U3.19 (27_A13_SCK1)
/BUTTON_1: C24.1, R26.2, U3.4 (2_OUT2)
/BUTTON_2: C25.1, R27.2, U3.5 (3_LRCLK2)
/BUTTON_3: C26.1, R28.2, U3.12 (10_CS_MQSR)
/BUTTON_4: C27.1, R29.2, U3.13 (11_MOSI_CTX1)
/BUTTON_5: C36.1, R38.2, U3.7 (5_IN2)
/BUTTON_6: C37.1, R39.2, U3.6 (4_BCLK2)
/BUTTON_7: C38.1, R40.2, U3.22 (30_CRX3)
/BUTTON_8: C39.1, R41.2, U3.23 (31_CTX3)
/BUTTON_9: C44.1, R46.2, U3.25 (33_MCLK2)
/BUTTON_10: C45.1, R47.2, U3.9 (7_RX2_OUT1A)
/BUTTON_11: C46.1, R48.2, U3.27 (35_TX8)
/BUTTON_12: C47.1, R49.2, U3.28 (36_CS)
/BUTTON_13: C52.1, R54.2, U3.29 (37_CS)
/BUTTON_14: C53.1, R55.2, U3.26 (34_RX8)
/LED1_OUT: J2.2, R17.2
/LED1_SIG: U1.8 (1A4), U3.3 (1_TX1_CTX2_MISO1)
/LED2_OUT: J6.2, R9.2
/LED2_SIG: U1.6 (1A3), U3.2 (0_RX1_CRX2_CS1)
/LED3_OUT: J10.2, R18.2
/LED3_SIG: U1.4 (1A2), U3.8 (6_OUT1D)
/LED4_OUT: J14.2, R10.2
/LED4_SIG: U1.2 (1A1), U3.10 (8_TX2_IN1)
/LED5_OUT: J3.2, R19.2
/LED5_SIG: U1.11 (2A1), U3.45 (23_A9_CRX1_MCLK1)
/LED6_OUT: J7.2, R11.2
/LED6_SIG: U1.13 (2A2), U3.44 (22_A8_CTX1)
/LED7_OUT: J11.2, R20.2
/LED7_SIG: U1.15 (2A3), U3.41 (19_A5_SCL)
/LED8_OUT: J15.2, R12.2
/LED8_SIG: U1.17 (2A4), U3.40 (18_A4_SDA)
/LED9_OUT: J4.2, R21.2
/LED9_SIG: U2.8 (1A4), U3.39 (17_A3_TX4_SDA1)
/LED10_OUT: J8.2, R13.2
/LED10_SIG: U2.6 (1A3), U3.38 (16_A2_RX4_SCL1)
/LED11_OUT: J12.2, R22.2
/LED11_SIG: U2.4 (1A2), U3.37 (15_A1_RX3_SPDIF_IN)
/LED12_OUT: J16.2, R14.2
/LED12_SIG: U2.2 (1A1), U3.36 (14_A0_TX3_SPDIF_OUT)
/LED13_OUT: J5.2, R23.2
/LED13_SIG: U2.11 (2A1), U3.11 (9_OUT1C)
/LED14_OUT: J9.2, R15.2
/LED14_SIG: U2.13 (2A2), U3.16 (24_A10_TX6_SCL2)
/LED15_OUT: J13.2, R24.2
/LED15_SIG: U2.15 (2A3), U3.17 (25_A11_RX6_SDA2)
/LED16_OUT: J17.2, R16.2
/LED16_SIG: U2.17 (2A4), U3.24 (32_OUT1B)
/SERIAL_A: D7.2 (A2), J40.8, U4.8 (A)
/SERIAL_B: D5.1 (A1), J40.7, U4.7 (B)
/SERIAL_IN: U3.20 (28_RX7), U4.2 (RO)
/SERIAL_OUT: U3.21 (29_TX7), U4.3 (DI)
/SERIAL_Y: D3.1 (A1), J40.1, R7.1, U4.5 (Y)
/SERIAL_Z: C57.2, D4.2 (A2), J40.2, U4.6 (Z)
GND: C1.1, C2.1, C3.1, C4.1, C8.1, C9.1, C10.1, C11.1, C12.2, C13.2, C14.1, C15.1, C16.1, C17.1, C18.1, C19.1, C20.1, C21.1, C22.2, C23.1, C24.2, C25.2, C26.2, C27.2, C28.2, C29.2, C30.2, C31.2, C32.2, C33.2, C34.2, C35.2, C36.2, C37.2, C38.2, C39.2, C40.2, C41.2, C42.2, C43.2, C44.2, C45.2, C46.2, C47.2, C48.2, C49.2, C50.2, C51.2, C52.2, C53.2, C55.2, C61.1, D3.2 (A2), D4.1 (A1), D5.2 (A2), D7.1 (A1), J2.3, J3.3, J4.3, J5.3, J6.3, J7.3, J8.3, J9.3, J10.3, J11.3, J12.3, J13.3, J14.3, J15.3, J16.3, J17.3, J18.2, J19.2, J20.2, J21.2, J22.3, J23.3, J24.3, J25.3, J26.2, J27.2, J28.2, J29.2, J30.3, J31.3, J32.3, J33.3, J34.2, J35.2, J36.2, J37.2, J38.2, J39.2, J40.3, J40.4, J40.5, J40.6, R1.2, R2.2, R3.2, R4.2, R25.2, R34.1, R35.1, R36.1, R37.1, R50.1, R51.1, R52.1, R53.1, U1.10 (GND), U2.10 (GND), U3.1 (GND), U3.34 (GND), U3.47 (GND), U4.4 (GND); also elsewhere on the board
unnamed: C57.1, R7.2
unnamed: D6.1 (K), R25.1
unnamed: J18.1, R26.1
unnamed: J19.1, R27.1
unnamed: J20.1, R28.1
unnamed: J21.1, R29.1
unnamed: J22.2, R30.1
unnamed: J23.2, R31.1
unnamed: J24.2, R32.1
unnamed: J25.2, R33.1
unnamed: J26.1, R38.1
unnamed: J27.1, R39.1
unnamed: J28.1, R40.1
unnamed: J29.1, R41.1
unnamed: J30.2, R42.1
unnamed: J31.2, R43.1
unnamed: J32.2, R44.1
unnamed: J33.2, R45.1
unnamed: J34.1, R46.1
unnamed: J35.1, R47.1
unnamed: J36.1, R48.1
unnamed: J37.1, R49.1
unnamed: J38.1, R54.1
unnamed: J39.1, R55.1
unnamed: R1.1, U1.1 (1~OE)
unnamed: R2.1, U2.1 (1~OE)
unnamed: R3.1, U1.19 (2~OE)
unnamed: R4.1, U2.19 (2~OE)
unnamed: R9.1, U1.14 (1Y3)
unnamed: R10.1, U1.18 (1Y1)
unnamed: R11.1, U1.7 (2Y2)
unnamed: R12.1, U1.3 (2Y4)
unnamed: R13.1, U2.14 (1Y3)
unnamed: R14.1, U2.18 (1Y1)
unnamed: R15.1, U2.7 (2Y2)
unnamed: R16.1, U2.3 (2Y4)
unnamed: R17.1, U1.12 (1Y4)
unnamed: R18.1, U1.16 (1Y2)
unnamed: R19.1, U1.9 (2Y1)
unnamed: R20.1, U1.5 (2Y3)
unnamed: R21.1, U2.12 (1Y4)
unnamed: R22.1, U2.16 (1Y2)
unnamed: R23.1, U2.9 (2Y1)
unnamed: R24.1, U2.5 (2Y3)

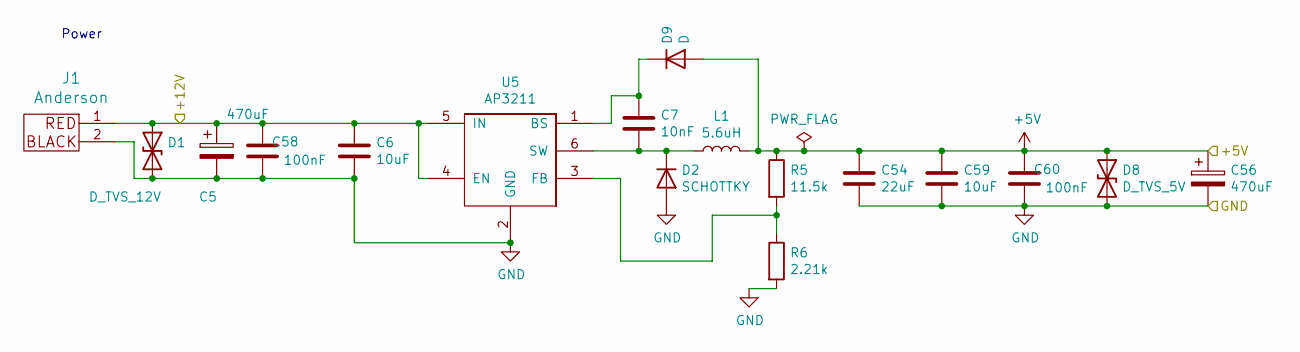
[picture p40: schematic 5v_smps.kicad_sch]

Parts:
C5, C56: 470uF; CP_Radial_D10.0mm_P5.00mm; MPN ESC477M035AH4EA
C6, C59: 10uF; C_0805_2012Metric; LCSC C15850
C7: 10nF; C_0402_1005Metric; LCSC C15195
C54: 22uF; C_1206_3216Metric; LCSC C12891
C58, C60: 100nF; C_0402_1005Metric; LCSC C307331
D1: D_TVS_12V; D_SMB; MPN SMBJ13CA
D2: SCHOTTKY; D_SMA; LCSC C8678
D8: D_TVS_5V; D_SMB; MPN SMBJ6.0CD-M3/H
D9: D; D_SMA; LCSC C8678
J1: Anderson; Anderson_1336G1_right_angle_bottom_two
L1: 5.6uH; L_Taiyo-Yuden_NR-60xx; MPN NR6028T6R0M
R5: 11.5k; R_0603_1608Metric; MPN RMCF0603FT11K5
R6: 2.21k; R_0603_1608Metric; MPN RC1608F2211CS
U5: AP3211; SOT-23-6; MPN AP3211KTR-G1

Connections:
+5V: C54.1, C56.1, C59.1, C60.1, D8.1 (A1), D9.2 (A), L1.2, R5.1; also elsewhere on the board
+12V: C5.1, C6.1, C58.1, D1.1 (A1), J1.1, U5.4 (EN), U5.5 (IN)
GND: C5.2, C6.2, C54.2, C56.2, C58.2, C59.2, C60.2, D1.2 (A2), D2.2 (A), D8.2 (A2), J1.2, R6.2, U5.2 (GND); also elsewhere on the board
unnamed: C7.1, D9.1 (K), U5.1 (BS)
unnamed: C7.2, D2.1 (K), L1.1, U5.6 (SW)
unnamed: R5.2, R6.1, U5.3 (FB)

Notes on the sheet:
Power



Board: 2 copper layers, 154.5 x 105.0 mm, 174 parts (126 on the bottom side), 111 nets.

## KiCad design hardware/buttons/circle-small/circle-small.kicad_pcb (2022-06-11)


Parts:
C1: 10uF; C_0603_1608Metric; LCSC C96446
C2: 100nF; C_0402_1005Metric; LCSC C307331
D1, D2, D3, D4, D5, D6, D7, D8, D9: WS2812B; LED_WS2812B_PLCC4_5.0x5.0mm_P3.2mm; LCSC C2761796
H1, H2, H3: MountingHole; MountingHole_3.2mm_M3
J1, J2: Conn_01x03; PinHeader_1x03_P2.54mm_Vertical
R1, R2: 33; R_0603_1608Metric; LCSC C23140

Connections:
/SIG_IN: J1.2, R1.1
/SIG_OUT: J2.2, R2.2
GND: C1.2, C2.2, D1.3 (VSS), D2.3 (VSS), D3.3 (VSS), D4.3 (VSS), D5.3 (VSS), D6.3 (VSS), D7.3 (VSS), D8.3 (VSS), D9.3 (VSS), J1.1, J2.1
unnamed: D1.2 (DOUT), D2.4 (DIN)
unnamed: D1.4 (DIN), R1.2
unnamed: D2.2 (DOUT), D3.4 (DIN)
unnamed: D3.2 (DOUT), D4.4 (DIN)
unnamed: D4.2 (DOUT), D5.4 (DIN)
unnamed: D5.2 (DOUT), D6.4 (DIN)
unnamed: D6.2 (DOUT), D7.4 (DIN)
unnamed: D7.2 (DOUT), D8.4 (DIN)
unnamed: D8.2 (DOUT), D9.4 (DIN)
unnamed: D9.2 (DOUT), R2.1
VCC: C1.1, C2.1, D1.1 (VDD), D2.1 (VDD), D3.1 (VDD), D4.1 (VDD), D5.1 (VDD), D6.1 (VDD), D7.1 (VDD), D8.1 (VDD), D9.1 (VDD), J1.3, J2.3


Board: 2 copper layers, 49.1 x 46.8 mm, 18 parts (0 on the bottom side), 14 nets.

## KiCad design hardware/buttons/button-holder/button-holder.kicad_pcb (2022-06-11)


Board: 2 copper layers, 27.0 x 28.0 mm, 6 parts (0 on the bottom side), 2 nets.

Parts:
H1, H2, H3, H4: MountingHole; MountingHole_3.2mm_M3
J1: Conn_01x02; PinHeader_1x02_P2.54mm_Vertical
SW1: SW_SPST; SW_Tactile_SPST_TL6300

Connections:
unnamed: J1.1, SW1.1 (A)
unnamed: J1.2, SW1.2 (B)

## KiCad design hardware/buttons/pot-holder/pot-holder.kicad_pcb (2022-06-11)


Board: 2 copper layers, 146.0 x 22.0 mm, 7 parts (1 on the bottom side), 3 nets.

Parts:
C1: C; C_0603_1608Metric_Pad1.08x0.95mm_HandSolder
H1, H2, H3, H4: MountingHole; MountingHole_3.2mm_M3
J1: Conn_01x03; PinHeader_1x03_P2.54mm_Vertical
RV1: R_Potentiometer; Potentiometer_Bourns_PTB01X3_Single_Slide

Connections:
unnamed: C1.1, J1.1, RV1.1
unnamed: C1.2, J1.3, RV1.3
unnamed: J1.2, RV1.2

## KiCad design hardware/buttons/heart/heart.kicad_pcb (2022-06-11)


Board: 2 copper layers, 99.4 x 70.3 mm, 25 parts (0 on the bottom side), 20 nets.

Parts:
C1: 10uF; C_0603_1608Metric
C2: 100nF; C_0402_1005Metric
D1, D2, D3, D4, D5, D6, D7, D8, D9, D10, D11, D12, D13, D14, D15: WS2812B; LED_WS2812B_PLCC4_5.0x5.0mm_P3.2mm
H1, H2, H3, H4: MountingHole; MountingHole_3.2mm_M3
J1, J2: Conn_01x03; PinHeader_1x03_P2.54mm_Vertical
R1, R2: 33; R_0603_1608Metric

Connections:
/SIG_IN: J1.2, R1.1
/SIG_OUT: J2.2, R2.2
GND: C1.2, C2.2, D1.3 (VSS), D2.3 (VSS), D3.3 (VSS), D4.3 (VSS), D5.3 (VSS), D6.3 (VSS), D7.3 (VSS), D8.3 (VSS), D9.3 (VSS), D10.3 (VSS), D11.3 (VSS), D12.3 (VSS), D13.3 (VSS), D14.3 (VSS), D15.3 (VSS), J1.1, J2.1
unnamed: D1.2 (DOUT), D2.4 (DIN)
unnamed: D1.4 (DIN), R1.2
unnamed: D2.2 (DOUT), D4.4 (DIN)
unnamed: D3.2 (DOUT), D5.4 (DIN)
unnamed: D4.2 (DOUT), D6.4 (DIN)
unnamed: D5.2 (DOUT), D7.4 (DIN)
unnamed: D6.2 (DOUT), D8.4 (DIN)
unnamed: D7.2 (DOUT), D9.4 (DIN)
unnamed: D10.2 (DOUT), D12.4 (DIN)
unnamed: D8.2 (DOUT), D10.4 (DIN)
unnamed: D11.2 (DOUT), D13.4 (DIN)
unnamed: D9.2 (DOUT), D11.4 (DIN)
unnamed: D12.2 (DOUT), D14.4 (DIN)
unnamed: D13.2 (DOUT), D15.4 (DIN)
unnamed: D3.4 (DIN), D14.2 (DOUT)
unnamed: D15.2 (DOUT), R2.1
VCC: C1.1, C2.1, D1.1 (VDD), D2.1 (VDD), D3.1 (VDD), D4.1 (VDD), D5.1 (VDD), D6.1 (VDD), D7.1 (VDD), D8.1 (VDD), D9.1 (VDD), D10.1 (VDD), D11.1 (VDD), D12.1 (VDD), D13.1 (VDD), D14.1 (VDD), D15.1 (VDD), J1.3, J2.3

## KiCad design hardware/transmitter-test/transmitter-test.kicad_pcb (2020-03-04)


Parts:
C1, C2, C3, C4, C5: .1uF; C_0603_1608Metric_Pad1.05x0.95mm_HandSolder
J1: Conn_01x03; PinHeader_1x03_P2.54mm_Vertical
J2, J3, J4, J7, J8, J9, J10: Conn_01x02; PinHeader_1x02_P2.54mm_Vertical
J5, J6: RJ45; RJ45_Amphenol_54602-x08_Horizontal
U1: AM26LS31x; SOIC-16_3.9x9.9mm_P1.27mm

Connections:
+5V: C1.1, J1.3, U1.4 (G), U1.16 (VCC)
GND: C1.2, C2.2, C3.2, C4.2, C5.2, J1.1, J2.1, J3.1, J4.1, J5.3, J5.4, J6.3, J6.4, J7.1, J8.1, J9.1, J10.1, U1.8 (GND)
LED1_IN: J1.2, U1.1 (1A)
LED1_Y: J5.1, U1.2 (1Y)
LED1_Z: J5.2, U1.3 (1Z)
LED2_IN: J2.2, U1.7 (2A)
LED2_Y: J5.7, U1.6 (2Y)
LED2_Z: J5.8, U1.5 (2Z)
LED3_IN: J3.2, U1.9 (3A)
LED3_Y: J6.1, U1.10 (3Y)
LED3_Z: J6.2, U1.11 (3Z)
LED4_IN: J4.2, U1.15 (4A)
LED4_Y: J6.7, U1.14 (4Y)
LED4_Z: J6.8, U1.13 (4Z)
PIR1: C2.1, J5.6, J7.2
PIR2: C3.1, J5.5, J8.2
PIR3: C4.1, J6.6, J9.2
PIR4: C5.1, J6.5, J10.2


Board: 2 copper layers, 53.0 x 31.8 mm, 16 parts (0 on the bottom side), 18 nets.

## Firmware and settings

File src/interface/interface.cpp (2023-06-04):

#include <EasyTransfer.h>
#include <FastLED.h>
#include <Watchdog_t4.h>
#include <debounce-filter.h>
#include <median-filter.h>
#include <quantization-filter.h>

#include <vector>

#include "Controls.hpp"
#include "IdleEffect.hpp"
#include "InterfaceParamController.hpp"
#include "LowPowerEffect.hpp"
#include "Pole.hpp"
#include "TestLightsEffect.hpp"
#include "interface/InterfaceController.hpp"

// Behavior flags
constexpr bool kDebugFlashAtBoot = true;

enum class RunType {
  NORMAL,
  DEBUG_LIGHTS,
  DEBUG_CONTROLS,
};

const constexpr RunType run_mode = RunType::NORMAL;

// Buttons
const int kEffect1 = 2;
const int kEffect2 = 3;
const int kEffect3 = 10;
const int kEffect4 = 11;
const int kEffect5 = 5;
const int kEffect6 = 4;
const int kEffect7 = 30;
const int kOption1 = 31;
const int kOption2 = 33;
const int kShift = 7;
const int kBeat = 35;
const int kPause = 36;
const int kButton13 = 37;
const int kButton14 = 34;

const std::vector<int> BUTTON_PINS = {
    kEffect1, kEffect2, kEffect3, kEffect4, kEffect5, kEffect6,  kEffect7,
    kOption1, kOption2, kShift,   kBeat,    kPause,   kButton13, kButton14,
};

// Analog inputs
const int kAnalog1 = 38;
const int kAnalog2 = 20;
const int kAnalog3 = 40;
const int kAnalog4 = 41;
const int kAnalog5 = 26;
const int kAnalog6 = 21;
const int kAnalog7 = 39;
const int kAnalog8 = 27;

const std::vector<int> ANALOG_INPUT_PINS = {
    kAnalog1, kAnalog2, kAnalog3, kAnalog4, kAnalog5, kAnalog7, kAnalog8,
};

const std::vector<int> PCB_ORDER_INPUT_PINS = {
    kEffect1, kEffect5, kOption2, kAnalog1, kEffect2, kEffect6,
    kShift,   kAnalog2, kEffect3, kEffect7, kBeat,    kAnalog3,
    kEffect4, kOption1, kPause,   kAnalog4,
};

constexpr int kLed = 13;

std::vector<QuantizationFilter<uint16_t>> analog_inputs;
std::vector<uint16_t> prev_analog_inputs;

EasyTransfer brain_out;
EasyTransfer brain_in;
ControlsIn brain_out_data;
ControlsOut brain_in_data;

// FastLED Teensy 4.1 parallel output pin strings:
// [1, 0, 24, 25, 19, 18, 14, 15, 17, 16, 22, 23,] 20, 21, 26, 27
// 10, 12, 11, 13, [6, 9, 32, 8,] 7
// 37, 36, 35, 34, 39, 38, 28, 31, 30

/*
Index  LED_number
The # on the right is the index in PCB_ORDER_INPUT_PINS starting at 1
Bank 1:
 0  1
 1  2
 2 14
 3 15
 4  7
 5  8
 6 12
 7 11
 8  9
 9 10
10  6
11  5

Bank 2:
0  3
1 13
2 16
3  4
*/

const int kMaxLedsPerStrip = 15;
const int kStripsPerBank1 = 12;
const int kStripsPerBank2 = 4;

const int kBank1FirstPin = 1;
const int kBank2FirstPin = 6;

Buttons::Bank1 bank1;
Buttons::Bank2 bank2;
Poles poles;
Buttons buttons(bank1, bank2);
InterfaceParamController param_controller{brain_out_data};
InterfaceController interface_controller{poles, buttons, param_controller};
IdleEffect idle_effect{poles, buttons, param_controller};
LowPowerEffect low_power_effect{poles, buttons, param_controller};
TestLightsEffect test_lights_effect{poles, buttons, param_controller};

uint8_t effect_last_pressed = 0;

WDT_T4<WDT1> watchdog;

void WatchdogCallback() { Serial.println("Warning: watchdog not fed"); }

void setup() {
  pinMode(kLed, OUTPUT);
  digitalWrite(kLed, HIGH);

  Serial.begin(115200);
  // while(!Serial) {}
  Serial.println("Booting...");
  pinMode(13, OUTPUT);

  for (auto button_pin : BUTTON_PINS) {
    pinMode(button_pin, INPUT_PULLUP);
  }

  for (auto analog_pin : ANALOG_INPUT_PINS) {
    pinMode(analog_pin, INPUT);
    analog_inputs.push_back(QuantizationFilter<uint16_t>(
        filter_functions::ForAnalogReadDynamic(analog_pin), /*bucket_size=*/4,
        /*hysteresis=*/4));
    prev_analog_inputs.push_back(analogRead(analog_pin));
  }

  analogReadResolution(10);

  Serial.println("Pins initialized");

  FastLED.addLeds<kStripsPerBank1, WS2812, kBank1FirstPin, GRB>(
      bank1.data(), kMaxLedsPerStrip);
  FastLED.addLeds<kStripsPerBank2, WS2812, kBank2FirstPin, GRB>(
      bank2.data(), kMaxLedsPerStrip);
  FastLED.showColor(CRGB::Black);
  // colordance-brain power supply can source 1A at 5V. Leave lots of margin for
  // its load (the RS422 is power-hungry).
  FastLED.setMaxPowerInVoltsAndMilliamps(5, 1000);
  FastLED.setMaxRefreshRate(30);

  Serial.println("FastLED initialized");
  delay(100);

  if (kDebugFlashAtBoot) {
    // Quickly flash all of the controls R, G, B. This facilitates checking that
    // all LEDS work on startup.
    FastLED.showColor(CRGB(255, 0, 0));
    delay(250);
    FastLED.showColor(CRGB(0, 255, 0));
    delay(250);
    FastLED.showColor(CRGB(0, 0, 255));
    delay(250);
    FastLED.showColor(CRGB::Black);
  }

  Serial.println("Local assets initialized. Beginning serial communication...");

  // Sets speed for serial port and brain communication
  // decrease this if flaky
  Serial7.begin(kSerialBaud);
  brain_out.begin(details(brain_out_data), &Serial7);
  brain_in.begin(details(brain_in_data), &Serial7);

  digitalWrite(kLed, LOW);

  WDT_timings_t config;
  config.trigger = 5;  /* in seconds, 0->128 */
  config.timeout = 10; /* in seconds, 0->128 */
  config.callback = WatchdogCallback;
  watchdog.begin(config);
}

void readControls() {
  brain_out_data.alive = (millis() / 500) % 2;
  brain_out_data.button_mask = 0;
  bool effect_pressed = false;

  for (uint8_t button_index = 0; button_index < BUTTON_PINS.size();
       button_index++) {
    uint16_t val = !digitalRead(BUTTON_PINS[button_index]) << button_index;
    if (val && !effect_pressed) {
      effect_last_pressed = button_index;
      effect_pressed = true;
    }
    brain_out_data.button_mask |= val;
  }

  for (uint8_t i = 0;
       i < ANALOG_INPUT_PINS.size() && i < ControlsIn::kAnalogInputSize; i++) {
    analog_inputs[i].Run();
    brain_out_data.analog_inputs[i] = analog_inputs[i].GetFilteredValue() / 4;
  }
}

void debugControls() {
  for (uint8_t input_index = 0; input_index < 16; input_index++) {
    CRGB color;
    if ((input_index % 4) < 3) {
      bool button_pressed = !digitalRead(PCB_ORDER_INPUT_PINS[input_index]);
      color = button_pressed ? CRGB(0, 255, 255) : CRGB(255, 0, 0);
    } else {
      uint16_t input = analogRead(PCB_ORDER_INPUT_PINS[input_index]);
      color = CHSV(HUE_RED, 255 - input, input);
    }
    for (uint8_t light_index = 0; light_index < kMaxLedsPerStrip;
         light_index++) {
      // TODO: write to the buttons
    }
  }
  FastLED.show();
  delay(10);
}

// Flash the lights RED, GREEN, BLUE
void debugLights() {
  CRGB color = CRGB(255, 0, 0);
  if ((millis() / 1000) % 3 == 1) {
    color = CRGB(0, 255, 0);
  } else if ((millis() / 1000) % 3 == 2) {
    color = CRGB(0, 0, 255);
  }
  FastLED.showColor(color);
  delay(10);
}

void loop() {
  switch (run_mode) {
    case RunType::NORMAL:
      readControls();
      break;

    case RunType::DEBUG_CONTROLS:
      debugControls();
      break;

    case RunType::DEBUG_LIGHTS:
      debugLights();
      break;
  }

  // Wait to receive data before sending, so that we don't interrupt the brain
  // while its writing out LEDs.
  if (brain_in.receiveData()) {
    digitalWrite(kLed, (millis() / 500) % 2);
    brain_out.sendData();

    // Run the main effect here on the interface - we keep this in sync with the
    // one on the brain, so that this one can output to the buttons.
    switch (brain_in_data.runner_state) {
      case RunnerState::NORMAL:
        interface_controller.Step();
        param_controller.Step();
        break;

      case RunnerState::IDLE:
        idle_effect.Step();
        break;

      case RunnerState::LOW_POWER:
        low_power_effect.Step();
        break;

      case RunnerState::TEST_LIGHTS:
        test_lights_effect.Step();
        break;
    }
    FastLED.show();
  }
  digitalWrite(13, brain_in_data.alive);
  watchdog.feed();
  // for (int i = 0; i < 6; i++) {
  //   Serial.print(brain_out_data.analog_inputs[i] / 4);
  //   Serial.print(" ");
  // }
  // Serial.println();
}

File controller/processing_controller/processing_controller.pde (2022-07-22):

import processing.serial.*;
import controlP5.*;  

SerialPortHandler serialPortHandler;
ControlP5 cp5;
DropdownList serialPortSelector;

void setup() {
  size(1000, 1000);
  cp5 = new ControlP5(this);
  serialPortHandler = new SerialPortHandler(this);
  serialPortSelector = cp5.addDropdownList("serialPortSelector")
    .setPosition(0, 0)
    .onChange(serialPortHandler)
    .addItem("none", null)
    .addItems(Serial.list())
    .close();
  
   /* Poll stuff */
   
  MagicEffectButtons effect = new MagicEffectButtons(cp5, "e");
  
  MagicSlider s1 = new MagicSlider(cp5, "v", "S1", 0, 255);
  s1.getControl().setPosition(333, 530);
  
  MagicSlider s2 = new MagicSlider(cp5, "w", "S2", 0, 255);
  s2.getControl().setPosition(533, 530);
  
  MagicButtons b1 = new MagicButtons(cp5, "x", "Option 1");
  b1.getControl().setPosition(205, 517);
  b1.getControl().setHeight(75);
  b1.getControl().setWidth(75);
  
  MagicButtons b2 = new MagicButtons(cp5, "y", "Option 2");
  b2.getControl().setPosition(720, 517);
  b2.getControl().setHeight(75);
  b2.getControl().setWidth(75);
  

  
  MagicButtons reverse = new MagicButtons(cp5, "s", "Shift");
  reverse.getControl().setPosition(279, 650);
  reverse.getControl().setHeight(83);
  reverse.getControl().setWidth(83);
  
  MagicButtons shiftLoop = new MagicButtons(cp5, "l", "Shift Loop");
  shiftLoop.getControl().setPosition(221, 629);
  shiftLoop.getControl().setHeight(33);
  shiftLoop.getControl().setWidth(33);
  
  MagicButtons beat = new MagicButtons(cp5, "b", "BEAT");
  beat.getControl().setPosition(409, 621);
  beat.getControl().setHeight(141);
  beat.getControl().setWidth(182);
  
  MagicButtons pause = new MagicButtons(cp5, "p", "Pause");
  pause.getControl().setPosition(637, 650);
  pause.getControl().setHeight(83);
  pause.getControl().setWidth(83);
  
}

// When using the simulator, if we output lines too quickly, the simulator will
// become increasingly behind. This is used to rate-limit.
int outputAt = 0;
final int OUTPUT_EVERY = 50;

void draw() {
  background(128);
  if (SerialPortHandler.controlsModified) {
    outputAt = millis() + OUTPUT_EVERY;
    SerialPortHandler.controlsModified = false;
  } else if (millis() > outputAt) {
    print("\n");
    outputAt = millis() + OUTPUT_EVERY;
  }
}

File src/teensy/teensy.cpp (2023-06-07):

#include <Entropy.h>
#include <TimeLib.h>
#include <Watchdog_t4.h>

#include <ColordanceTypes.hpp>
#include <memory>

#include "Buttons.hpp"
#include "Controls.hpp"
#include "Effect.hpp"
#include "FakeLogger.hpp"
#include "FakeParamController.hpp"
#include "LocalButtonController.hpp"
#include "Runner.hpp"
#include "TeensyEnvironmentController.hpp"
#include "TeensyLightController.hpp"
#include "TeensySdLogger.hpp"
#include "interface/InterfaceController.hpp"
#include "serial-param-controller.h"

namespace {

Buttons::Bank1 bank1;
Buttons::Bank2 bank2;
auto light_controller = TeensyLightController();
Buttons buttons(bank1, bank2);
TeensyEnvironmentController environment_controller;
// FakeParamController param_controller;
SerialParamController param_controller;
TeensySdLogger logger{param_controller, environment_controller};
Runner runner(light_controller.get_poles(), buttons, param_controller,
              environment_controller, logger);

uint32_t print_at = 0;

WDT_T4<WDT1> watchdog;

}  // namespace

void WatchdogCallback() {
  static constexpr uint32_t kBufferSize = 200;
  static char buffer[kBufferSize];
  Serial.println("Warning: watchdog not fed");
  int ret = snprintf(buffer, kBufferSize, "%10lu, Watchdog warning", millis());
  if (ret > 0) {
    logger.Log(buffer);
  }
}

time_t GetTeensyTime() { return Teensy3Clock.get(); }

void SetRTC(time_t time) {
  Teensy3Clock.set(time);
  setTime(time);
}

void setup() {
  Serial.begin(115200);

  Serial.println("Brain initializing...");

  setSyncProvider(GetTeensyTime);

  // Take epoch time, in seconds
  // SetRTC(0);

  // See
  // https://forum.pjrc.com/threads/61974-Teensy4-x-Entropy-library-documentation
  Entropy.Initialize();
  randomSeed(Entropy.random(0, 32767));

  WDT_timings_t config;
  config.trigger = 5;  /* in seconds, 0->128 */
  config.timeout = 10; /* in seconds, 0->128 */
  config.callback = WatchdogCallback;
  watchdog.begin(config);

  Serial.print("Initializing logger... ");
  if (logger.Begin()) {
    Serial.println("done.");
  } else {
    Serial.println("FAILED.");
  }

  Serial.println("Brain initialization complete");
}

void loop() {
  if (millis() > print_at) {
    Serial.print("Alive: ");
    Serial.println(millis());
    print_at = millis() + 5000;
  }
  runner.Step();
  param_controller.SetRunnerState(runner.State());
  light_controller.WriteOutLights();
  watchdog.feed();
}

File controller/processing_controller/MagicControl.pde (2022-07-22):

public abstract class MagicControl<T extends Controller> implements CallbackListener {
  // This is the token that identifies the param for this control - this is used to communicate this param to the Colordance program. Probably a single character.
  protected final String paramIdentifier;
  protected final T control;

  MagicControl(String paramIdentifier, T control) {
    this.paramIdentifier = paramIdentifier;
    this.control = control;

    control.onChange(this);
  }

  protected int getValue() {
    return (int) control.getValue();
  }

  void controlEvent(CallbackEvent theEvent) {
    SerialPortHandler.controlsModified = true;
    String output = String.format("%s: %d\n", paramIdentifier, getValue()); 
    if (SerialPortHandler.getPort() == null) {
      print(output);
    } else {
      SerialPortHandler.getPort().write(output);
    }
  }

  T getControl() {
    return control;
  }
}

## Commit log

2019-11-24 Add a simulator
    Shows 6 lights in a circle.
    [resources.cfg]
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2019-11-28 Finish implementing FastLedLightController.
    This now runs on Arduino. Also added an upload target to the Arduino
    makefile.
2019-11-28 Add tests for the effects.
    This tests stability (by running for 12 simulated hours) and power
    consumption.
2019-11-28 Fail power test if average or max power is too high
2019-12-01 Add runtime option to use real or fake millis().
    This fixes the simulator.
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2019-12-08 Upgrade to 4x4 array of LEDs for Arduino.
    Also update RotateThree to take advantage of this.
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2019-12-14 Add a param controller.
    Adds a param controller interface, and an implementation using Arduino
    serial.
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2020-03-04 Add pole node board v1.0
    [pole-node-B_Cu.gbr, pole-node-B_Mask.gbr, pole-node-B_Paste.gbr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]
2020-03-04 Add transmitter test board v1.0
    [transmitter-test-B_Cu.gbr, transmitter-test-B_Mask.gbr, transmitter-test-B_Paste.gbr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]
2020-03-08 Fix arduino-cli config to work with latest version (v0.9.0)
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2021-03-20 Migrate to PlatformIO.
    This uses Platformio to build Arduino code, instead of a terrible
    hacked-together Makefile.
2021-04-24 Start adding brain PCB
    [colordance-brain.kicad_pcb, colordance-brain.sch]
2021-04-27 Update pole node to v1.1
    This adds lots of TVS diode, more decoupling, bulk caps on 5v and 12v
    lines. Also adds pass-through Anderson connector.
    [colordance-brain.sch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]
2021-05-20 Pole node v1.2.
    Same circuit as v1.1, but with all connectors on the same side.
    [pole-node-B_Cu.gbr, pole-node-B_Mask.gbr, pole-node-B_Paste.gbr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]
2021-05-20 More work on colordance-brain
    - Define hierarchical sheet for RS422 output
    - Update power supply
    [colordance-brain.sch, rs422_output.sch]
2021-05-20 Colordance brain v1.0
    [colordance-brain-B_Cu.gbr, colordance-brain-B_Mask.gbr, colordance-brain-B_Paste.gbr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]
2021-05-28 Add HTML bom
    [colordance-brain.kicad_pcb, pole-node.kicad_pcb]
2021-06-12 Add PCB spacer
    [pcb-spacer.scad, pcb-spacer.stl]
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2021-09-08 Add quarter inch washer
    [pcb-spacer.scad, quarter inch washer.stl]
2021-09-08 Fix teensy bug
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2021-09-09 Fix first 4 LED port numbers
    [teensy.cpp]
2022-04-15 Add schematic for circle button
    [circle-button.kicad_pcb, circle-button.sch]
2022-04-15 Random hardware changes
    [colordance-brain.sch, pole-node.csv, pole-node.sch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]
2022-04-24 Add schematic for interface-brain
    [interface-brain.kicad_pcb, interface-brain.kicad_sch]
2022-04-25 Assign footprints and part numbers
    [interface-brain.kicad_sch]
2022-04-26 Start interface component placement
    [interface-brain.kicad_pcb]
2022-04-27 Continue interface brain layout
    [interface-brain.kicad_pcb, interface-brain.kicad_sch]
2022-04-28 Interface brain layout almost done
    [interface-brain.kicad_pcb, interface-brain.kicad_sch]
2022-04-29 interface-brain v1.0 complete
    [interface-brain-B_Cu.gbl, interface-brain-B_Mask.gbs, interface-brain-B_Paste.gbp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]
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2022-04-30 Add square button
    [circle-button.kicad_pcb, circle-button.sch, heart.csv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]
2022-04-30 Add heart button
    [heart-B_Cu.gbl, heart-B_Mask.gbs, heart-B_Paste.gbp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]
2022-04-30 Add slider
    [slider-B_Cu.gbl, slider-B_Mask.gbs, slider-B_Paste.gbp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]
2022-04-30 Add mounting holes
    [heart-B_Cu.gbl, heart-B_Mask.gbs, heart-B_Paste.gbp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]
2022-04-30 Add big and small buttons
    [circle-big-B_Cu.gbl, circle-big-B_Mask.gbs, circle-big-B_Paste.gbp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]
2022-04-30 Add button and pot holder PCBs
    [button-holder-B_Cu.gbl, button-holder-B_Mask.gbs, button-holder-B_Paste.gbp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]
2022-05-09 Add STEP and STLs for interface PCBs
    [button-holder PCB.stl, button-holder.step, circle-big v1.stl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]
2022-05-10 Add beginning of interface code.
    This has the pin defs and basic SPI logic.
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2022-05-16 Continue fixing debug controls
    [interface.cpp]
2022-05-18 Fix button holder pinout
    [button-holder-B_Cu.gbl, button-holder-B_Mask.gbs, button-holder-B_Paste.gbp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]
2022-06-06 Fix case in include paths
2022-06-07 Add 3D model for pot holder
    [pot-holder.step]
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2022-06-11 Try to fix teensy lights
    [button-holder PCB.stl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]
2022-06-15 Fix pole-node port mappings
    [teensy.cpp]
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2022-06-20 Convert colordance-brain to KiCAD 6
    [colordance-brain.kicad_pcb, colordance-brain.kicad_sch, rs422_output.kicad_sch]
2022-06-20 colordance-brain v1.1
    - Switch from SPI to serial-over-RS422 for communication with the
    interface. Using the Teensy 4.1 as a SPI peripheral did not work. Using
    RS422 will allow us to place the interface far away (e.g. 50ft) from the
    brain.
    - Also break out an extra serial port, e.g. for music playing?
    - Change protection for most I/O pins to resistor + cap instead of TVS
    diode
    - Add a builtin button, for activating test modes
    [colordance-brain-B_Cu.gbl, colordance-brain-B_Cu.gbr, colordance-brain-B_Mask.gbr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]
2022-06-20 Move power supply to subsheet
    [5v_smps.kicad_sch, colordance-brain.kicad_sch, rs422_output.kicad_sch]
2022-06-23 Update interface-brain schematic
    [5v_smps.kicad_sch, interface-brain.kicad_sch]
2022-06-24 interface-brain v1.1:
    - Switch to serial-over-RS422 for comms with colordance-brain
    - Add 12v supply + 5V SMPS
    [5v_smps.kicad_sch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]
2022-07-03 Update effect integration test.
    - Cycle through the pole-effects
    - Add calculation for max pole power
    - Migrate from unique_ptr to raw pointers, since that more closely
    matches how this works on device
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2022-07-10 Update simulator to display the LEDs directly.
    This migrates from using Ogre to SDL2.
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2022-07-12 Fix names of serial param controllers.
    [teensy.cpp]
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2022-07-22 Fix lag in simulator
    [MagicControl.pde, SerialPortHandler.pde, processing_controller.pde]
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2022-07-27 Start updating brain for v1.2
    [5v_smps.kicad_sch, colordance-brain.kicad_pcb, colordance-brain.kicad_sch]
2022-07-28 colordance-brain hardware v1.2:
    - Fix interface RJ45 port orientation
    - Add a third local PIR port
    - Fix interface to use a serial port, not a CAN port
    - Add a 470uF cap for the 3v3 rail
    [colordance-brain-B_Cu.gbl, colordance-brain-B_Mask.gbs, colordance-brain-B_Paste.gbp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]
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2022-08-02 Fix test lights pin
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2022-08-02 Fix LED output corruption isses
    Some LEDs were not being updated/written to. This is due to some
    interaction between receiving serial data and the Teensy FastLED
    library. The teensy serial ports use interrupts and a 4-byte buffer, and
    FastLED uses DMA with interrupts. This change fixes the issue by
    enforcing timing in the brain and interface code. It has a strict
    sequence, where the brain will receive the serial data at a specific
    time (when it is not writing out LEDs).
    [interface.cpp, teensy-model.cpp, teensy.cpp]
2022-08-03 Default battery to full in fake environment controller.
    This fixes the model going into low-power mode when using the firefly board.
2022-08-04 Fix logger tests
    Also change the logger to log seconds, not milliseconds.
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2022-08-09 Code review fixes & lower power fixes
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2022-08-22 Sort of fix interface.
    [interface.cpp]
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2023-05-29 pole-node v1.3:
    - Modify to support JLC assembly
    - Change buck converter to one in stock at JLC
    - Add protection resistors to IO
    - Add PTC fuse and crowbar diode, for reverse voltage protection
    - Fix label for grid lights
    [pole-node-B_Cu.gbl, pole-node-B_Cu.gbr, pole-node-B_Mask.gbr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]
2023-05-29 Update colordance-brain PCB files to KiCAD 7
    [5v_smps.kicad_sch, colordance-brain.kicad_pcb, colordance-brain.kicad_sch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]
2023-05-29 Update colordance-brain schematic for v1.3: JLC assembly
    [5v_smps.kicad_sch, colordance-brain.kicad_sch, rs422_output.kicad_sch]
2023-05-29 Update colordance-brain to 1.3: JLC assembly (completed)
    [5v_smps.kicad_sch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]
2023-05-29 Fix pole-node v1.3 footprint for XL1509 SMPS
    [pole-node-B_Cu.gbl, pole-node-B_Mask.gbs, pole-node-B_Paste.gbp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]
2023-05-29 Fix colordance-brain v1.3 footprint for XL1509 SMPS
    [5v_smps.kicad_sch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]
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2023-05-29 Fix teensy light controller pins
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2023-05-29 Fix bug where MovingPoles wrote to an invalid button index.
2023-05-29 Fix tests and re-enable battery checking
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2023-06-04 Fix watchdog log message
    [teensy.cpp]
2023-06-04 Once again, fix logging format strings
    [teensy.cpp]
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
